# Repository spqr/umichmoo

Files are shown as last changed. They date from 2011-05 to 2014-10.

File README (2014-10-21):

https://spqr.eecs.umich.edu/moo/

For licensing information, see license.txt.

This code is known to work only with IAR Embedded Workbench, including the
Kickstart (code size limited) edition available from TI.

= List of Compatible Readers =

* Impinj Speedway
* Impinj Speedway Revolution
* ThingMagic Mercury 5
* ThingMagic Mercury 5e
* ThingMagic Mercury 6
* Michael Buettner's GNU Radio gen2_rfid reader (YMMV)

See README.usage for information on compiling and flashing the moo.

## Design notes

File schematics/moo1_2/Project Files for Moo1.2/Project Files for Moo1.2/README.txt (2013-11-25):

Design Parameters

Material Type: FR4
Finish Thickness: 31 mil
Copper weight(inner): 1 oz
Copper Weight(outer): 2 oz
Silk Screen Color: Yellow
Solder Mask Color: Blue
Surface Finishing: HASL
Would like Electrical Testing performed

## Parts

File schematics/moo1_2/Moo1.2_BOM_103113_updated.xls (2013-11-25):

BOM: Moo 1.2
Assembly Part Number/Revision: Moo Rev: 1.2
Customer Company Name: U of M / SPQR Lab
Date Updated: 10/31/13
 |  |  | (fill this column only in case you also give your own part numbers) |  |  |  |  |  |  |  | (fill this column only in case of consigned) | (fill this column only in case of consigned)
Item # | Qty/ bd | Reference designations | Customer Part # | Value | Size / Footprint | Part description/ specs | Manfacturer | Manufacturer Part # | Distributor | Distributor P/N | Quantity Required | Kit Quantity Shipped | ASSEMBLY / PROCUREMENT COMMENTS
1 | 2 | C1, C6 |  | 10uF | C0805 | CAP CER 10UF 16V 10% X5R 0805 | AVX Corporation | 0805YD106KAT2A | Digi-Key | 478-5165-1-ND |  |  | C6 is an 0402 capacitor
2 | 4 | C2, C4, C5, C13 |  | 0.1uF | C0402 | CAP CER 0.1UF 16V 10% X7R 0402 | TDK Corporation | C1005X7R1C104K | Digi-Key | 445-4952-1-ND |  |  | removed C9 part
3 | 6 | C10, C11, Cp1, Cp2, Cp3, Cp4 |  | 10pF | C0402 | CAP CER 10PF 50V 5% NP0 0402 | Murata Electronics | GRM1555C1H100JA01D | Digi-Key | 490-5921-1-ND
4 | 1 | C12 |  | 100pF | C0402 | CAP CER 100PF 50V 5% NP0 0402 | Murata Electronics | GRM1555C1H101JZ01D | Digi-Key | 490-6153-1-ND
5 | 2 | C3, C14, C20 |  | 1uF | C0402 | CAP CER 1UF 10V 10% X5R 0402 | Murata Electronics | GRM155R61A105KE15D | Digi-Key | 490-3890-1-ND |  |  | DNI C3
6 | 5 | Cs1, Cs2, Cs3, Cs4, Cs5 |  | 7pF | C0402 | Ceramic Capacitor - Standard, 7pF | Murata Electronics | GRM1555C1H7R0DZ01D | Digi-Key | 490-1277-1-ND
7 | 1 | CV1 |  | 7pF-30pF | C0603 | CAP TRIMMER 7-30PF 25V SMD | Sprague-Goodman (http://digikey.com/Suppliers/us/Sprague-Goodman.page?lang=en) | GKRP30066 | Digi-Key | SG2029CT-ND
8 | 5 | D1, D2, D3, D4, D5 |  |  | SOT-323 | DIODE SCHOTTKY DETECT SS SOT-323 | Avago Technologies | HSMS-285C-BLKG | Digi-Key | 516-2558-ND
9 | 2 | D6, D7 |  |  | SOD-523 | SCHOTTKY RECTIFIER, 30mA, 40V, SOD-523 | ON Semiconductor | RB751S40T1G | Newark | 10N9732
10 | 1 | DA1 |  |  | O603 | LED 630NM RED WTR CLR 0603 SMD | Rohm Semiconductor | SML-311UTT86 | Digi-Key | 511-1304-1-ND
11 | 1 | ED |  |  | SOD-523 | 5V Overvoltage Protection Zener | ON Semiconductor | ESD5Z3.3T1G | Digi-Key | ESD5Z3.3T1GOSCT-ND
12 | 1 | L1 |  | 6.8 nH | O603 | Inductor, 6.8nH | Panasonic | ELJ-RE6N8JFA | Digi-Key | PCD1971CT-ND
13 | 1 | MCU1 |  |  | 64-LQFP | 64PM MSP430F2618 | TI | MSP430F2618TPMR | Digi-Key | 296-22697-1-ND
14 | 1 | P1, P2, P3, P4 |  |  |  | Header, 10-Pin |  | 851-93-050-20-001000 | Digi-Key | ED8850-ND |  |  | DNI P1, P2, P3, P4
15 | 1 | Q1 |  |  | SOT23 | NPN 5 GHz wideband transistor | NXP Semiconductors | BFT25A,215 | Digi-Key | 568-1992-1-ND
16 | 3 | Q2, Q3, Q5 |  |  | SOT-723 | Power MOSFET N-CH 20V 750MA SOT-723 | ON Semiconductor | NTK3134NT1G | Digi-Key | NTK3134NT1GOSCT-ND
17 | 1 | Q4 |  |  | CMPAK-4 | Transistors RF MOSFET N-CH DUAL GATE 6V | NXP Semiconductors | BF1212WR,115 | Mouser | 771-BF1212WR
18 | 1 | R1 |  | 0 ohm | O402 | RES 0.0 OHM 1/10W JUMP 0402 SMD | Panasonic | ERJ-2GE0R00X | Digi-Key | P0.0JCT-ND
19 | 2 | R2, R4 |  | 1 k ohm | O402 | RES 1K OHM 1/10W 1% 0402 SMD | Panasonic | ERJ-2RKF1001X | Digi-Key | P1.00KLCT-ND
20 | 1 | R3 |  | 2k ohm | O402 | RES 2K OHM 1/10W 5% 0402 SMD | Panasonic | ERJ-2GEJ202X | Digi-Key | P2.0KJCT-ND
21 | 1 | R5 |  | 100 ohm | O402 | RES 100 OHM 1/16W 1% 0402 SMD | Vishay Dale | CRCW0402100RFKED | Digi-Key | 541-100LCT-ND
22 | 2 | R6, R17 |  | 33k ohm | O402 | RES 33.0K OHM 1/16W 1% 0402 SMD | Vishay Dale | CRCW040233K0FKED | Digi-Key | 541-33.0KLCT-ND
23 | 2 | R10, R11 |  | 10k ohm | O402 | RES 10K OHM 1/10W 1% 0402 SMD | Panasonic | ERJ-2RKF1002X | Digi-Key | P10.0KLCT-ND
24 | 1 | R16 |  | 200k ohm | O402 | RES 200K OHM 1/10W 1% 0402 SMD | Panasonic | ERJ-2RKF2003X | Digi-Key | P200KLCT-ND
25 | 1 | R18 |  | 1M ohm | O402 | RES 1M OHM 1/10W 1% 0402 SMD | Panasonic | ERJ-2RKF1004X | Digi-Key | P1.00MLCT-ND
26 | 1 | R19 |  | 66k ohm | O402 | RES 66.5K OHM 1/10W 1% 0402 SMD | Panasonic | ERJ-2RKF6652X | Digi-Key | P66.5KLCT-ND
27 | 1 | Rs |  | 10 ohm | O603 | RES 10 OHM 1/10W .1% 0603 SMD | Bourns Inc. | CRT0603-BY-10R0ELF | Digi-Key | CRT0603-BY-10R0ELFCT-ND
28 | 1 | TMP |  |  | 6-TSSOP (5 Lead) | Analog Temperature Sensor | TI | LM94021BIMGX/NOPB | Digi-Key | LM94021BIMGX/NOPBCT-ND
29 | 1 | U1 |  |  | SC70-5 | IC COMPARATOR LV LP OD SC70-5 | ON Semiconductor | NCS2200SQ2T2G | Digi-Key | NCS2200SQ2T2GOSCT-ND
30 | 2 | U2, U4 |  |  | 6-UFDFN | Level Shifter: 1-Bit Dual-Supply Non-Inverting Level Translator | ON Semiconductor | NLSV1T244MUTBG | Digi-Key | NLSV1T244MUTBGOSCT-ND
31 | 1 | U3 |  |  | SC82-AB | Ultra-Low Iq 150mA CMOS LDO Regulator with Enable, 1.8V, SC82-AB | ON Semiconductor | NCP583SQ18T1G | Digi-Key | NCP583SQ18T1GOSCT-ND
32 | 1 | U5 |  |  | 5-TSOP | IC VOLT DETECT CMOS 2.0V 5TSOP | ON Semiconductor | NCP300LSN20T1G | Digi-Key | NCP300LSN20T1GOSCT-ND
33 | 1 | U6 |  |  | SC70-5 | IC SWITCH SPST SC70-5 | TI | TS5A3166DCKR | Digi-Key | 296-17741-1-ND
34 | 1 | U7 |  |  | 8-SOIC | 4Mb 40MHz SPI 8-Lead SOIC Flash | TI | SST25WF040-40-5I-SAF | Digi-Key | SST25WF040-40-5I-SAF-ND
35 | 1 | XL1 |  |  | 16-LGA | IC ACCEL DIG LO PWR 3AX 16LGA | Analog Devices | ADXL362BCCZ-R2 | Digi-Key | ADXL362BCCZ-R2TR-ND |  |  | Updated XL to XL1
36 | 1 | Y1 |  |  | 3.2mm x 1.5mm | FC-135 Crystal D-K SE2416CT (MC-146), 32KHz Crystal | Epson | FC-135 32.7680KA-A3 | Digi-Key | SE2413CT-ND
37 | 1 | PCB |  |  |  | Moo 1.2 PCB
 | 62 | TOTAL # of Components
DNI LIST ("DO NOT INSTALL" LIST)
 | 1 | C3
 | 4 | P1,P2, P3, P4
 | 5 | TOTAL DNI

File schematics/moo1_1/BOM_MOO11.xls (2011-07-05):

Part Name / Manufacturer ID | Designator | Description | Quantity Needed | Quantity Available
0805YD106KAT2A | C1 | Ceramic Capacitor - Standard, 10uF | 10 | 22
C1005X7R1C104K | C2, C4, C5, C6, C9, C13 | Ceramic Capacitor - Standard, 0.1uF | 60 | 100
GRM1555C1H100JZ01D | C10, C11, Cp1, Cp2, Cp3, Cp4 | Ceramic Capacitor - Standard, 10pF | 60 | 69
GRM1555C1H101JZ01D | C12 | Ceramic Capacitor - Standard, 100pF | 10 | 20
GRM155R61A105KE15D | C14, C20 | Ceramic Capacitor - Standard, 1uF | 20 | 27
GRM1555C1H7R0DZ01D | Cs1, Cs2, Cs3, Cs4, Cs5 | Ceramic Capacitor - Standard, 7pF | 50 | 60
GKRP20066 | CV1 | Variable Capacitor 603 Compatible, DK: 490-2009 & SG2026CT, 5~20pF | 10 | 15
HSMS-285C-BLK | D1, D2, D3, D4, D5 | Agilent Schottky Diode, Bridge Quad, HSMS-285C, Vrrm = 2V | 50 | 100
RB751S40T1G | D6, D7 | Agilent Schottky Diode, Bridge Quad, HSMS-285C, Schottky Diode, Vr = 30V | 20 | 22
SML-311UTT86 | DA1 | LED 630NM RED WTR CLR 0603 SMD | 10 | 12
ESD5Z3.3T1G | ED | 5V Overvoltage Protection Zener | 10 | 15
ELJ-RE6N8JFA | L1 | Inductor, 6.8nH | 10 | 26
MSP430F2618TPMR | MCU1 | 64PM MSP430F2618 | 10 | 10
851-93-050-20-001000 | P1 | Header, 10-Pin | 100 | 125
BFT25A,215 | Q1 | NPN 5 GHz wideband transistor | 10 | 10
NTK3134NT1G | Q2, Q3, Q5 | Power MOSFET 20V, 890mA, single N-channel | 30 | 33
BF1212WR,115 | Q4 | N-Channel Dual Gate Transistor | 10 | 22
ERJ-2GE0R00X | R1 | Thick Film Chip Resistor, 0 ohm | 10 | 12
ERJ-2RKF1001X | R2, R4 | Thick Film Chip Resistor, 1k ohm | 20 | 30
ERJ-2GEJ202X | R3 | Thick Film Chip Resistor, 2k ohm | 10 | 12
CRCW0402100RFKED | R5 | Thick Film Chip Resistor, 100 ohm | 10 | 29
CRCW040233K0FKED | R6, R17 | Thick Film Chip Resistor, 33k ohm | 20 | 22
ERJ-2RKF1002X | R10, R11 | Thick Film Chip Resistor, 10k ohm | 20 | 22
ERJ-2RKF2003X | R16 | Thick Film Chip Resistor, 200k ohm | 10 | 22
ERJ-2RKF1004X | R18 | Thick Film Chip Resistor, 1M ohm | 10 | 30
ERJ-2RKF6652X | R19 | Thick Film Chip Resistor, 66k ohm | 10 | 12
CRT0603-BY-10R0ELF | Rs | RES 10 OHM 1/10W .1% 0603 SMD | 10 | 14
LM94021 | TMP | Temperature Sensor | 10 | 12
NCS2200SQ2T2G | U1 | On Semi 10uA Comparator | 10 | 12
NLSV1T244MUTBG | U2, U4 | Level Shifter: 1-Bit Dual-Supply Non-Inverting Level Translator | 20 | 22
NCP583SQ18T1G | U3 | Ultra-Low Iq 150mA CMOS LDO Regulator with Enable, 1.8V, SC82-AB | 10 | 10
S-1000C20-I4T1G | U5 | Ultra-small package High precision protection(SNT-4A) | 10 | 22
TS5A3166 | U6 | TI Analog Switch 100nA 1ohm Normally Open | 10 | 22
SST25WF040-40-5I-SAF | U7 | 4Mb 40MHz SPI 8-Lead SOIC Flash | 10 | 10
ADXL330 | XL | Analog Devices 3-axis accelerometer | 10 | 10
FC-135 32.7680KA-A3 | Y1 | FC-135 Crystal D-K SE2416CT (MC-146), 32KHz Crystal | 10 | 10
 | PCB | Moo 1.1 PCB | 10 | 10

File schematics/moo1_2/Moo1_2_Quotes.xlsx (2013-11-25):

PCB Quotes for Moo 1.2 | Note: Fab prices are going to be the same for 1-50 boards so we should order the maximum number at that rate and only assembly a couple |  |  |  |  |  |  |  |  | Assembly Price Not included
 |  |  |  |  |  | includes cost of components
Vendor | Turn-time Fab/Assembly | Fab Qty | Fabrication Price per board | Filled Vias? | Assemble Qty | Assembly Price | Tooling NRE? | Elec Testing? | Per Board Price | Total Price | Notes
Sunstone / Screaming Circuits | 5 days | 50 | $28.20 | No |  |  | 0 | yes | $28.20 | $1410.00 | plus 10% off on first order
Sierra Circuits | 5 days | 10 | $103.50 | No | 10 | $204.46 | 0 |  | $307.96 | $3079.60
Sierra Circuits | 7 days/5 days | 10 | $166.60 | Yes | 10 | $204.46 | 0 | yes | $371.06 | $3710.60
Sierra Circuits | 7 days/5 days | 10 | $166.60 | Yes | 2 | $608.99 | $0.00 | yes | $775.59 | $2883.98
Advanced Circuits (Custom Spec) | 7 days | 5 | $211.55 | No |  |  | $300 |  | $211.55 | $1057.75
PCB Fab Express | 5 days | 40 | $28.75 | No | 2 | $623.15 | 0 | Yes | $651.90 | $2396.30
PCB Fab Express | 5 days | 40 | $28.75 | no | 5 | $326.35 | $0.00 | yes | $355.10 | $2781.75
PCB Fab Express | 5 days | 40 | $28.75 | no | 10 | $219.43 | $0.00 | yes | $248.18 | $3344.30

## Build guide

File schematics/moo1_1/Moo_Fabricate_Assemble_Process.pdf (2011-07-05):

### Procedure of Fabricating and Assembling UMass Moo 1.1

Fabrication of Moo PCB:
1. To fabricate Moo PCBs, a bunch of Gerber files and some fabrication setting options are needed.
2. Contact a PCB factor to ask for a price, such as Sierra ProtoExpress. An email to rosyb@protoexpress.com can be sent to ask for a quotation. The email should include:
a) Quantity: such as 10, 100, 1000
b) # of days: such as 3, 4, 5, or more
c) Material Type: FR4
d) Finish thickness: 31 mil.
e) Copper Weight (inner): 1oz
f) Copper Weight (outer): 2oz
g) Silk Screen Color: White
h) Solder Mask Color: Green
i) Surface finishing: HASL
j) The Gerber files of Moo as attachments. The following contents will talk about how to obtain these files.
3. Download the Moo hardware design file package Moo1.1_03102011.zip from URL: http://www.github.com/spqr/umassmoo
4. Uncompressed the package, all gerber files needed to fabricate Moo PCBs are in the directory of Moo1.1_03102011\Gerbers.
5. If you want to do change of PCB layout and generate new gerber files, the following steps are needed:
a) Install a CAD software to design Schematics and PCBs, such as Altium Designer Winter 2009, or later version.
b) Use the Altium Designer software to edit the PCB layout of Moo.
c) Export new gerber files by following the tutorial of URL: http://www.olimex.com/pcb/How%20to%20export%20Gerber%20files%20from%20A ltium%20Designer%202009.pdf

Assemble of Moo:
1. Assembling is a procedure of soldering the parts onto the print circuit board. The obtaining of Moo PCB has already been described above. The other parts can be obtained in any one of two ways:
1) Purchase by yourself;
2) Some PCB assemblers provide service of parts purchasing/collecting service.

2. A bill of materials (BOM) is necessary to collecting the parts. The BOM of Moo is attached at the end of this document.
3. If you want to purchase the parts by yourself, you order everything listed in the BOM, otherwise, you need buy the service of the assembler, the factor which provides PCB assembling services for you.
4. Contact an assembler to ask for a quotation, such as Sierra ProtoExpress. In the email, the following documents should be sent as attachments:
d) PDF file of your PCB
e) Bill Of Materials (BOM), which includes part manufacturer #, designator, description, quantity.
5. Once got the PCBs and all parts, and quotation for assembling, mail the PCBs and parts in one box to assembler and just wait for the return of them.

Fabrication And Assembling of UMass Moo Version 1.1

Part Name / Manufacturer
ID | Designator | Description

Quantity
Needed

Quantity
Available
0805YD106KAT2A | C1 | Ceramic Capacitor - Standard, 10uF | 10 | 22
C1005X7R1C104K | C2, C4, C5, C6, C9, C13 | Ceramic Capacitor - Standard, 0.1uF | 60 | 100
GRM1555C1H100JZ01D | C10, C11, Cp1, Cp2, Cp3, Cp4 | Ceramic Capacitor - Standard, 10pF | 60 | 69
GRM1555C1H101JZ01D | C12 | Ceramic Capacitor - Standard, 100pF | 10 | 20
GRM155R61A105KE15D | C14, C20 | Ceramic Capacitor - Standard, 1uF | 20 | 27
GRM1555C1H7R0DZ01D | Cs1, Cs2, Cs3, Cs4, Cs5 | Ceramic Capacitor - Standard, 7pF | 50 | 60
GKRP20066 | CV1 | Variable Capacitor 603 Compatible, DK: 490-2009 & SG2026CT, 5~20pF | 10 | 15
HSMS-285C-BLK | D1, D2, D3, D4, D5 | Agilent Schottky Diode, Bridge Quad, HSMS-285C, Vrrm = 2V | 50 | 100
RB751S40T1G | D6, D7 | Agilent Schottky Diode, Bridge Quad, HSMS-285C, Schottky Diode, Vr = 30V | 20 | 22
SML-311UTT86 | DA1 | LED 630NM RED WTR CLR 0603 SMD | 10 | 12
ESD5Z3.3T1G | ED | 5V Overvoltage Protection Zener | 10 | 15
ELJ-RE6N8JFA | L1 | Inductor, 6.8nH | 10 | 26
MSP430F2618TPMR | MCU1 | 64PM MSP430F2618 | 10 | 10
851-93-050-20-001000 | P1 | Header, 10-Pin | 100 | 125
BFT25A,215 | Q1 | NPN 5 GHz wideband transistor | 10 | 10
NTK3134NT1G | Q2, Q3, Q5 | Power MOSFET 20V, 890mA, single N-channel | 30 | 33
BF1212WR,115 | Q4 | N-Channel Dual Gate Transistor | 10 | 22
ERJ-2GE0R00X | R1 | Thick Film Chip Resistor, 0 ohm | 10 | 12

Fabrication And Assembling of UMass Moo Version 1.1

ERJ-2RKF1001X | R2, R4 | Thick Film Chip Resistor, 1k ohm | 20 | 30
ERJ-2GEJ202X | R3 | Thick Film Chip Resistor, 2k ohm | 10 | 12
CRCW0402100RFKED | R5 | Thick Film Chip Resistor, 100 ohm | 10 | 29
CRCW040233K0FKED | R6, R17 | Thick Film Chip Resistor, 33k ohm | 20 | 22
ERJ-2RKF1002X | R10, R11 | Thick Film Chip Resistor, 10k ohm | 20 | 22
ERJ-2RKF2003X | R16 | Thick Film Chip Resistor, 200k ohm | 10 | 22
ERJ-2RKF1004X | R18 | Thick Film Chip Resistor, 1M ohm | 10 | 30
ERJ-2RKF6652X | R19 | Thick Film Chip Resistor, 66k ohm | 10 | 12
CRT0603-BY-10R0ELF | Rs | RES 10 OHM 1/10W .1% 0603 SMD | 10 | 14
LM94021 | TMP | Temperature Sensor | 10 | 12
NCS2200SQ2T2G | U1 | On Semi 10uA Comparator | 10 | 12
NLSV1T244MUTBG | U2, U4 | Level Shifter: 1-Bit Dual-Supply Non-Inverting Level Translator | 20 | 22
NCP583SQ18T1G | U3 | Ultra-Low Iq 150mA CMOS LDO Regulator with Enable, 1.8V, SC82-AB | 10 | 10
S-1000C20-I4T1G | U5 | Ultra-small package High precision protection(SNT-4A) | 10 | 22
TS5A3166 | U6 | TI Analog Switch 100nA 1ohm Normally Open | 10 | 22
SST25WF040-40-5I-SAF | U7 | 4Mb 40MHz SPI 8-Lead SOIC Flash | 10 | 10
ADXL330 | XL | Analog Devices 3-axis accelerometer | 10 | 10
FC-135 32.7680KA-A3 | Y1 | FC-135 Crystal D-K SE2416CT (MC-146), 32KHz Crystal | 10 | 10
| PCB | Moo 1.1 PCB | 10 | 10

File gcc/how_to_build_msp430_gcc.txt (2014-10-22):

1. Install the compiler for cross compiling

sudo add-apt-repository ppa:ubuntu-toolchain-r/test
sudo apt-get update
sudo apt-get install g++-4.9 gcc-4.9
(http://askubuntu.com/questions/428198/getting-installing-gcc-g-4-9-on-ubuntu)

2. Install tools required for cross compiling
sudo apt-get install libgmp3-dev libmpfr-dev libisl-dev libcloog-isl-dev libmpc-dev
(http://wiki.osdev.org/GCC_Cross-Compiler)

3. Setup build environmnet
mkdir -p $HOME/opt/cross
mkdir -p $HOME/src

export PREFIX="$HOME/opt/cross"
export TARGET=msp430-elf
export PATH="$PREFIX/bin:$PATH"

4. Build Binutils
cd $HOME/src
wget ftp://sourceware.org/pub/binutils/snapshots/binutils-2.24.51.tar.bz2
tar xvf binutils-2.24.51.tar.bz2
mkdir build_binutils_msp430
cd build_binutils_msp430
CC=/usr/bin/gcc-4.9 CXX=/usr/bin/g++-4.9 ../binutils-2.24.51/configure --prefix=${PREFIX} --target=${TARGET}
make -j8
make install
cd ..

5. Build GCC
wget http://mirror.csclub.uwaterloo.ca/gnu/gcc/gcc-4.9.1/gcc-4.9.1.tar.bz2
tar xvf gcc-4.9.1.tar.bz2
mkdir build_gcc_msp430
cd build_gcc_msp430
CC=/usr/bin/gcc-4.9 CXX=/usr/bin/g++-4.9 ../gcc-4.9.1/configure --prefix=${PREFIX} --target=${TARGET} --with-newlib --enable-languages=c,c++
make all-host -j8
make install-host
cd ..

6. Build Newlib
wget ftp://sourceware.org/pub/newlib/newlib-2.1.0.tar.gz
tar xvf newlib-2.1.0.tar.gz
mkdir build_newlib_msp430
cd build_newlib_msp430
CC=/usr/bin/gcc-4.9 CXX=/usr/bin/g++-4.9 ../newlib-2.1.0/configure --prefix=${PREFIX} --target=${TARGET} --disable-newlib-supplied-syscalls --enable-newlib-reent-small --disable-newlib-fvwrite-in-streamio --disable-newlib-fseek-optimization --disable-newlib-wide-orient --enable-newlib-nano-malloc --disable-newlib-unbuf-stream-opt --enable-lite-exit --enable-newlib-global-atexit --disable-nls
make
make install
cd ..

7. Build GCC round 2
cd build_gcc_msp430
make all-target
make install-target
cd ..

8. Build GDB
wget http://ftp.gnu.org/gnu/gdb/gdb-7.8.tar.xz
tar xvf gdb-7.8.tar.xz
mkdir build_gdb_msp430
cd build_gdb_msp430
CC=/usr/bin/gcc-4.9 CXX=/usr/bin/g++-4.9 ../gdb-7.8/configure --prefix=${PREFIX} --target=${TARGET}
make
make install

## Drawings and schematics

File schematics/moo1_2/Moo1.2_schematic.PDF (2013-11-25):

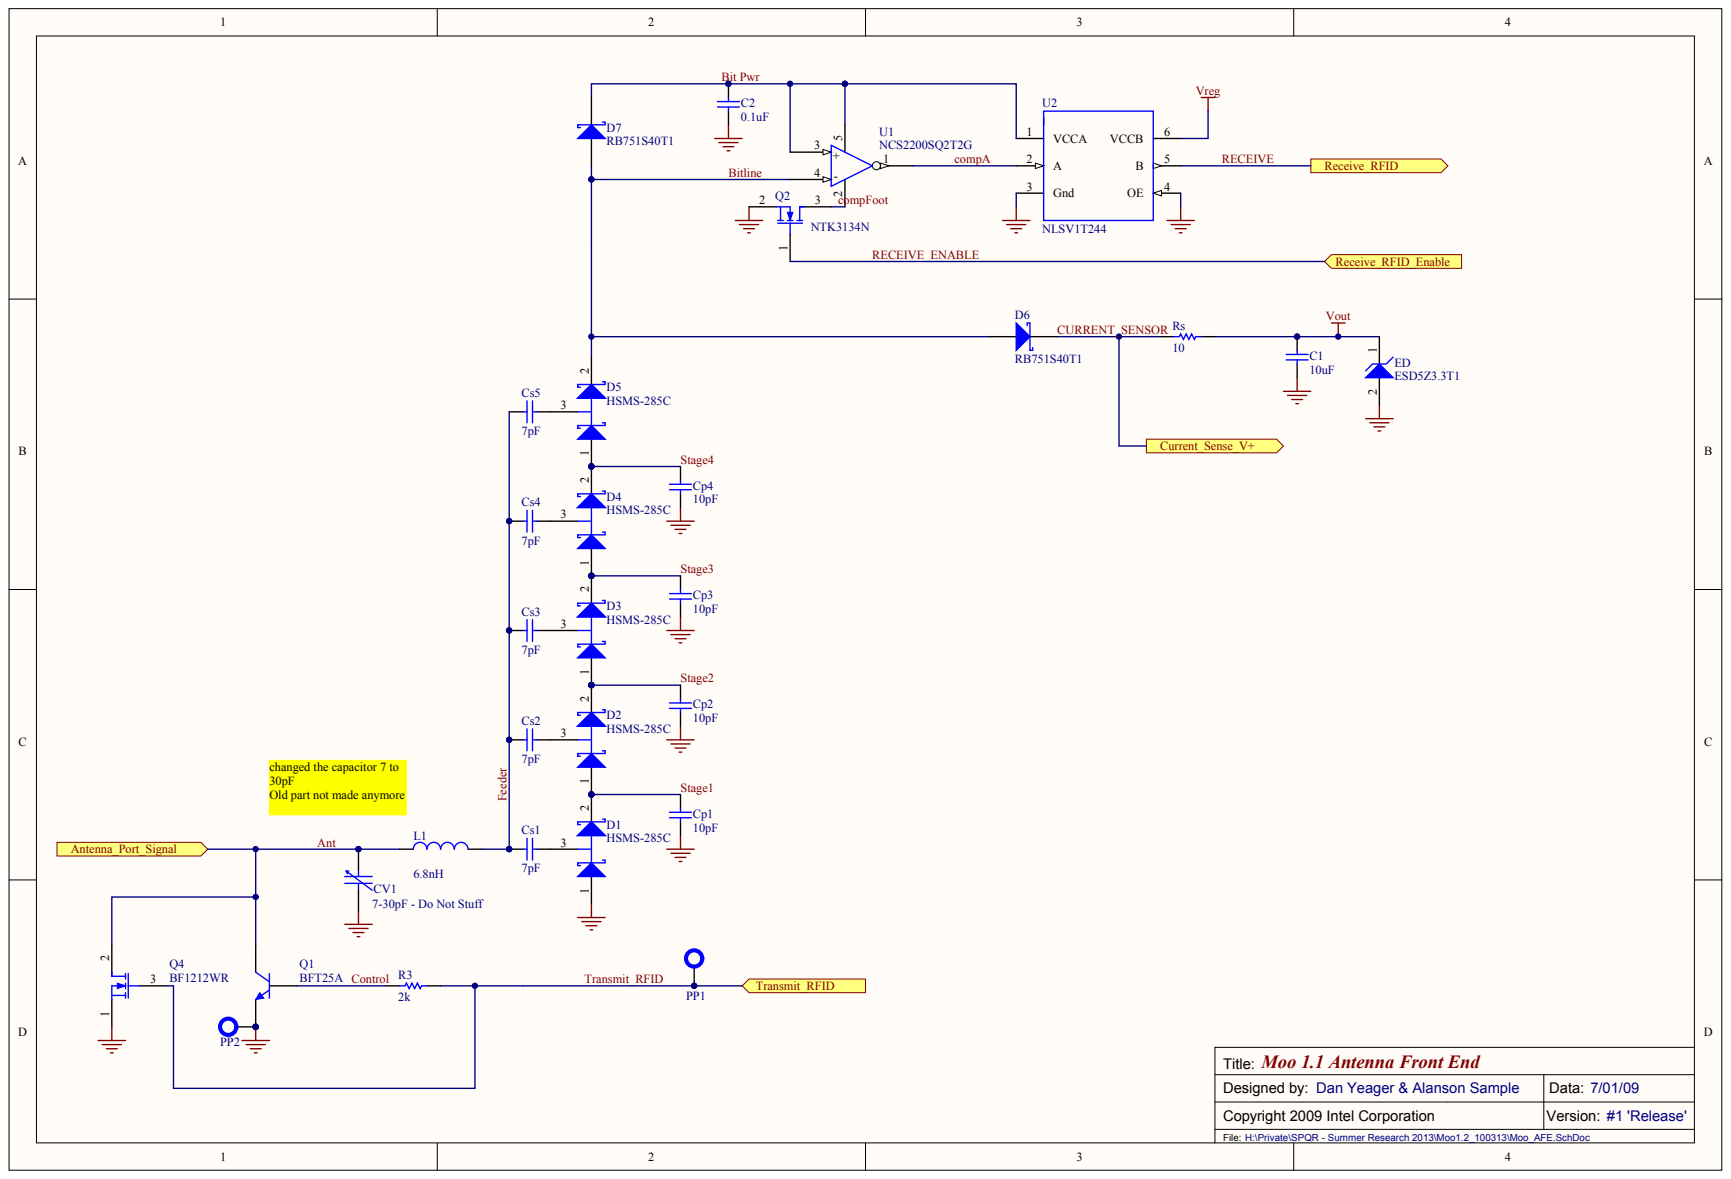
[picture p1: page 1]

changed the capacitor 7 to
Old part not made anymore

Title: Moo 1.1 Antenna Front End

Designed by: Dan Yeager & Alanson Sample | Data: 7/01/09

Copyright 2009 Intel Corporation | Version: #1 'Release'

H:\Private\SPQR - Summer Research 2013\Moo1.2_100313\Moo_AFE.SchDoc
File:

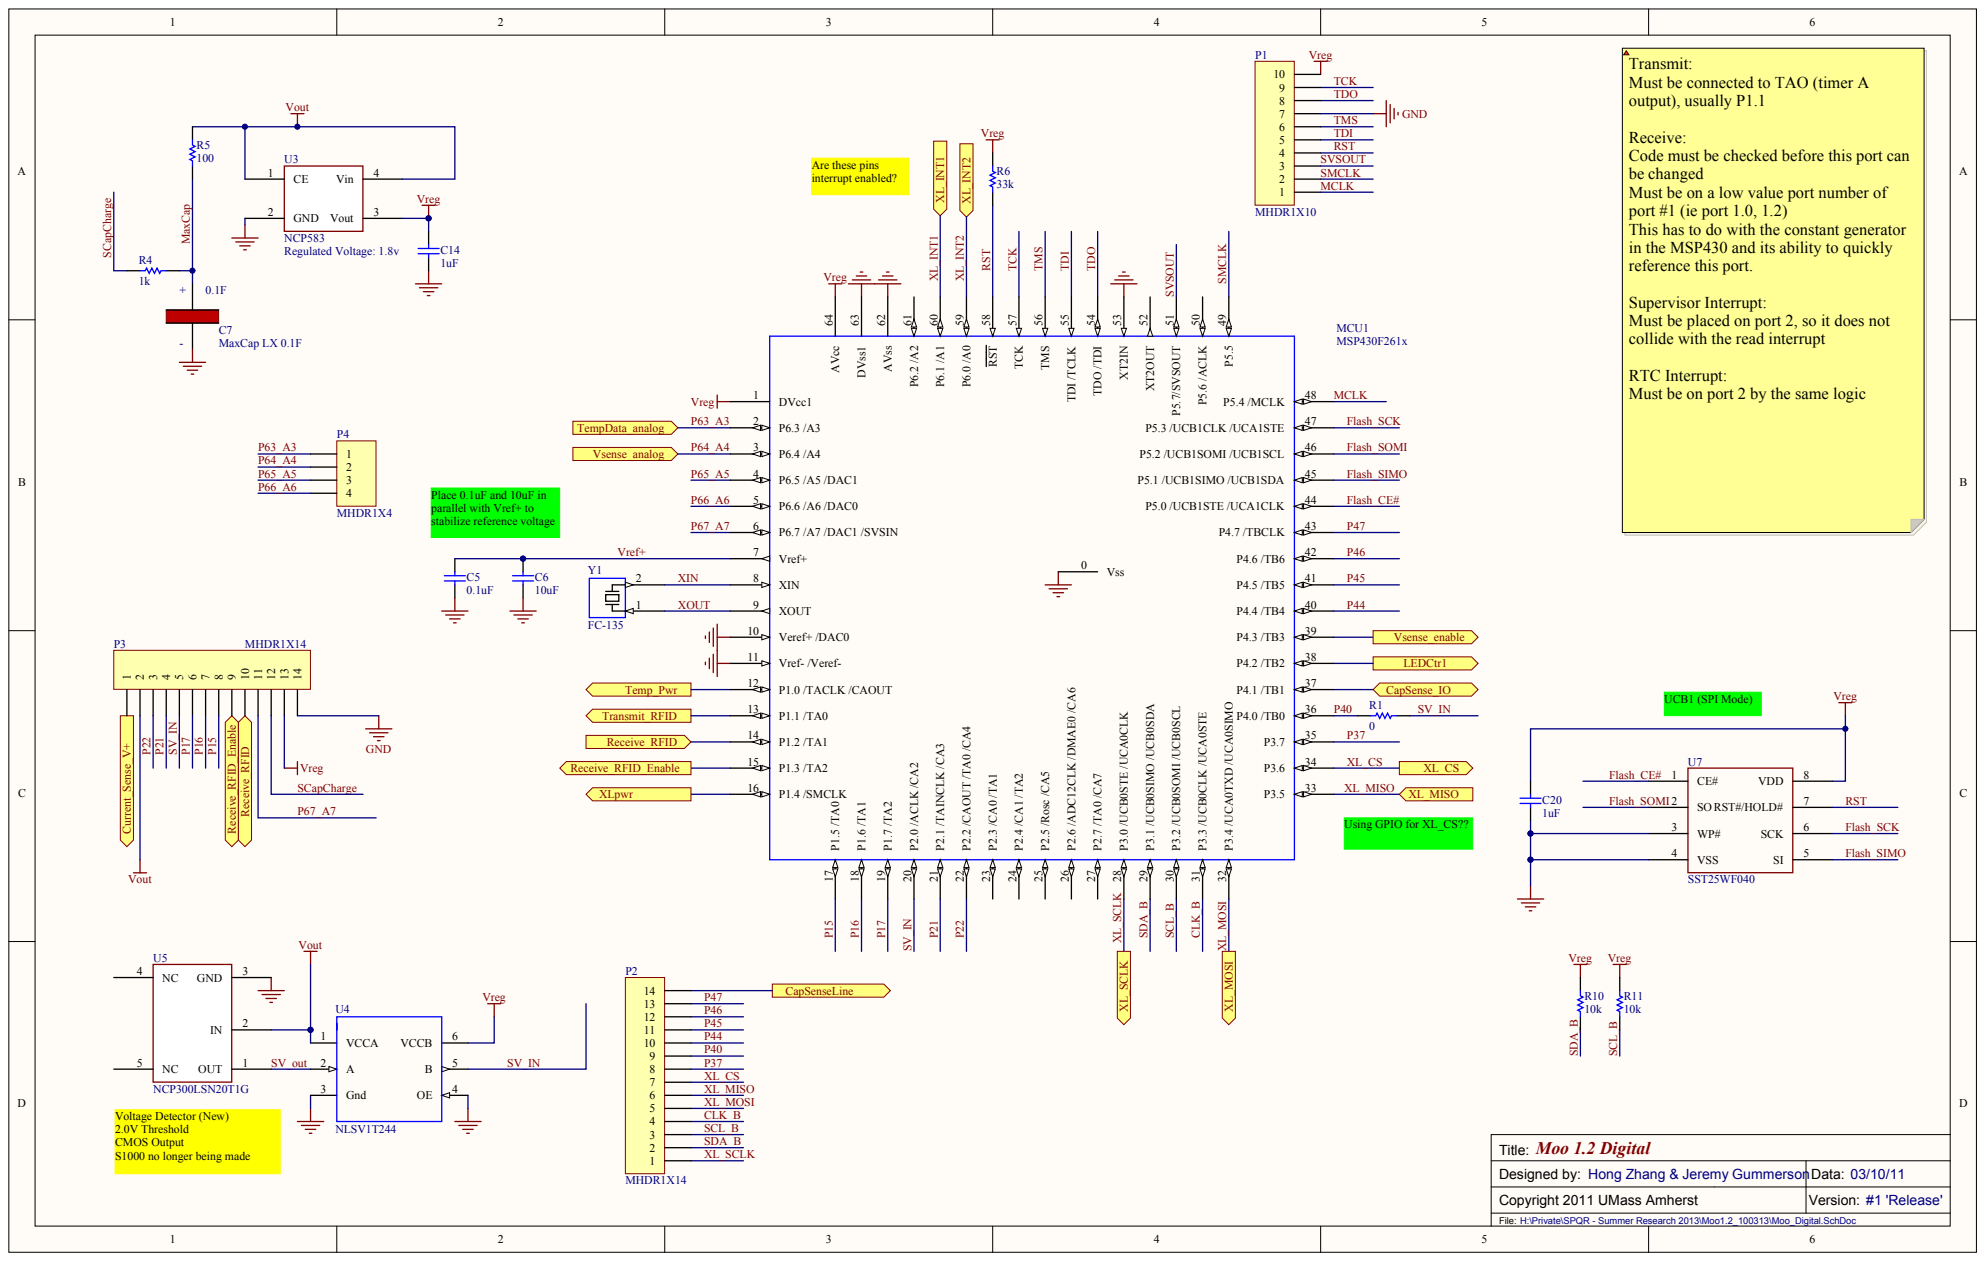
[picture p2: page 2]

Transmit:
Must be connected to TAO (timer A
output), usually P1.1

Receive:
Code
be changed
Must be on a low value port number of
port #1 (ie port 1.0, 1.2)
This has to do with the constant generator
in the MSP430 and its ability to quickly

must be checked before this port can

Supervisor Interrupt:
Must be placed on port 2, so it does not
collide with the read interrupt

RTC Interrupt:
Must be on port 2 by the same logic

Place 0.1uF and 10uF in
parallel with Vref+ to
stabilize reference v

Voltage Detector (New)
2.0V Threshold
CMOS Output
S1000 no longer being made

Designed by : Hong Zhang & Jerem y Gum mersonData: 03/10/11

Copyright 2011 UMass Amherst | Version: #1 'Release'

H:\Private\SPQR - Summer Research 2013\Moo1.2_100313\Moo_Digital.SchDoc
File:

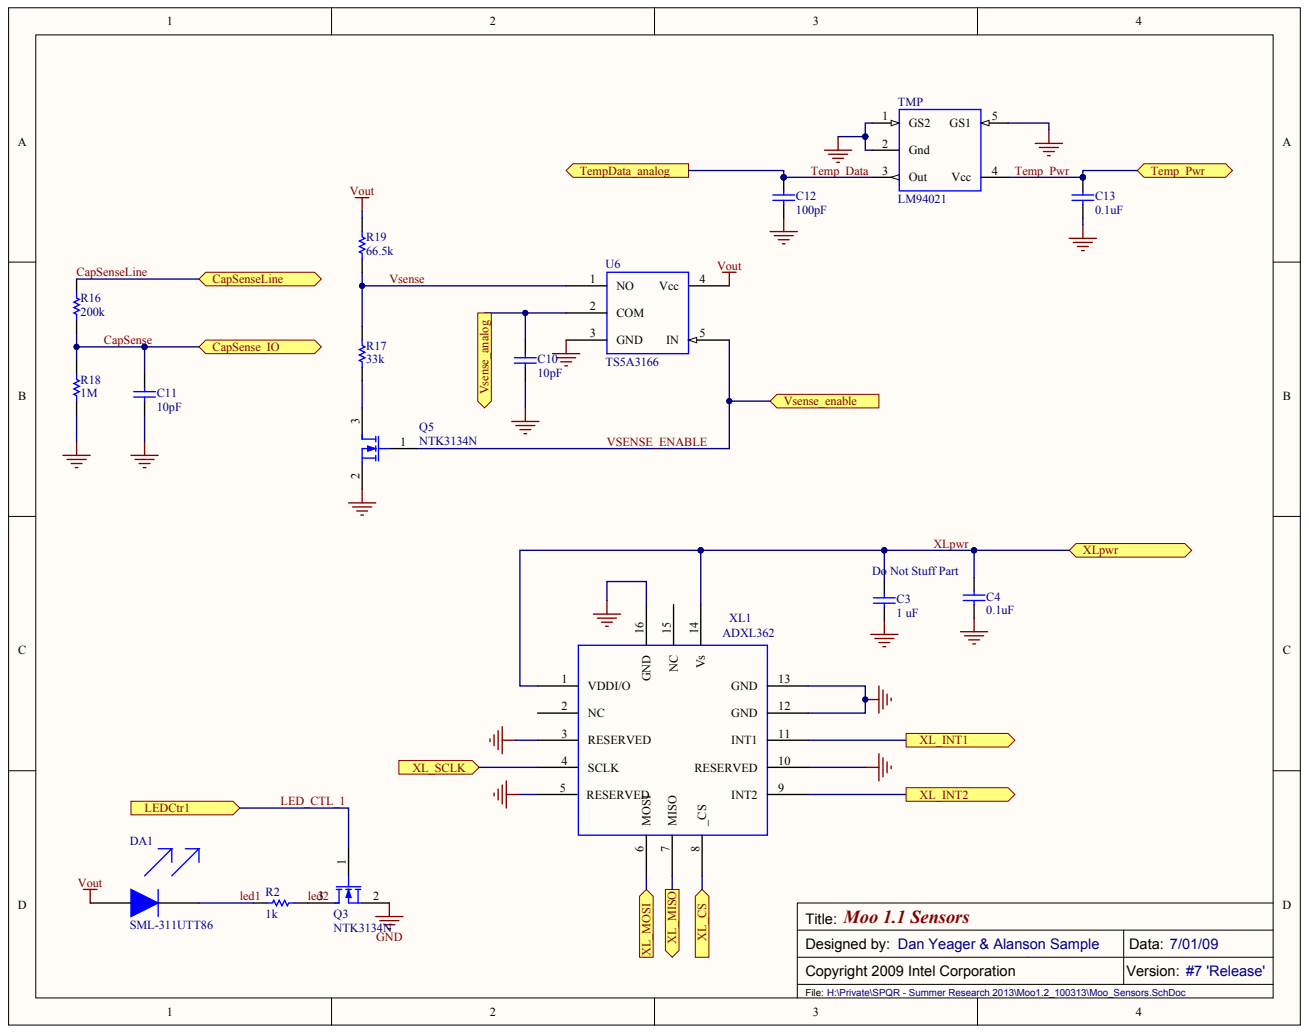
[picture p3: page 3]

COM 2 GND 3

Q5 NTK3134N | C10

Do Not Stuff Part

Designed by: Dan Yeager & Alanson Sample | Data: 7/01/09

Copyright 2009 Intel Corporation | Version: #7 'Release'

H:\Private\SPQR - Summer Research 2013\Moo1.2_100313\Moo_Sensors.SchDoc
File:

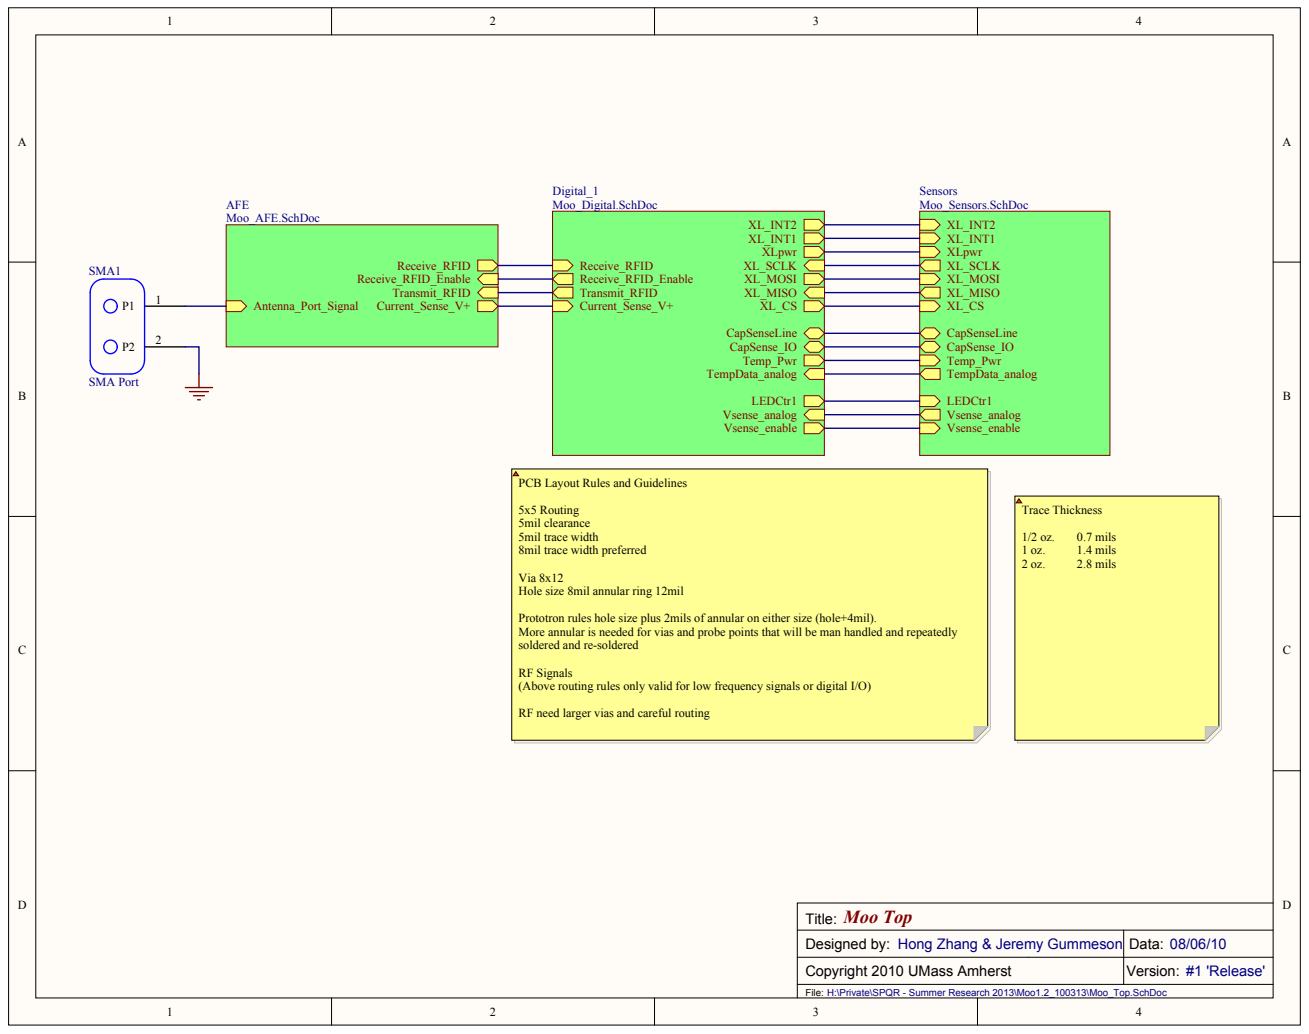
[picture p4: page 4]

PCB Layout Rules and Guidelines

Via 8x12
Hole size 8mil annular ring 12mil

Prototron rules hole size plus 2mils of annular on either size (hole+4mil).
More annular is needed for vias and probe points that will be man handled and repeatedly
soldered and re-soldered

RF Signals
(Above routing rules only valid for low frequency signals or digital I/O)

RF need larger vias and careful routing

Designed by: Hong Zhang & Jeremy Gummeson | Data: 08/06/10

Copyright 2010 UMass Amherst | Version: #1 'Release'

H:\Private\SPQR - Summer Research 2013\Moo1.2_100313\Moo_Top.SchDoc
File:

Component list | <Parameter Title not found>
Source Data From: | | Moo1.2.PrjPcb
Project: | | Moo1.2.PrjPcb
Variant: | | None
Report Date: | 10/9/2013 | 8:17:40 PM
Print Date: | 09-Oct-13 | 8:18:54 PM

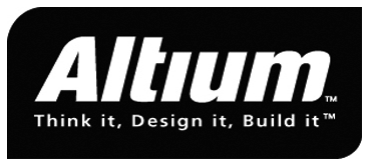
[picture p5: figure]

# | LibRef | #Column Name Error:Manufactu#Corerlumn Name Error:Manufact#uCor | lu mn Name Error:PartTyp | Description | Footprint | #Column Name Error:Package Reference | Quantity
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

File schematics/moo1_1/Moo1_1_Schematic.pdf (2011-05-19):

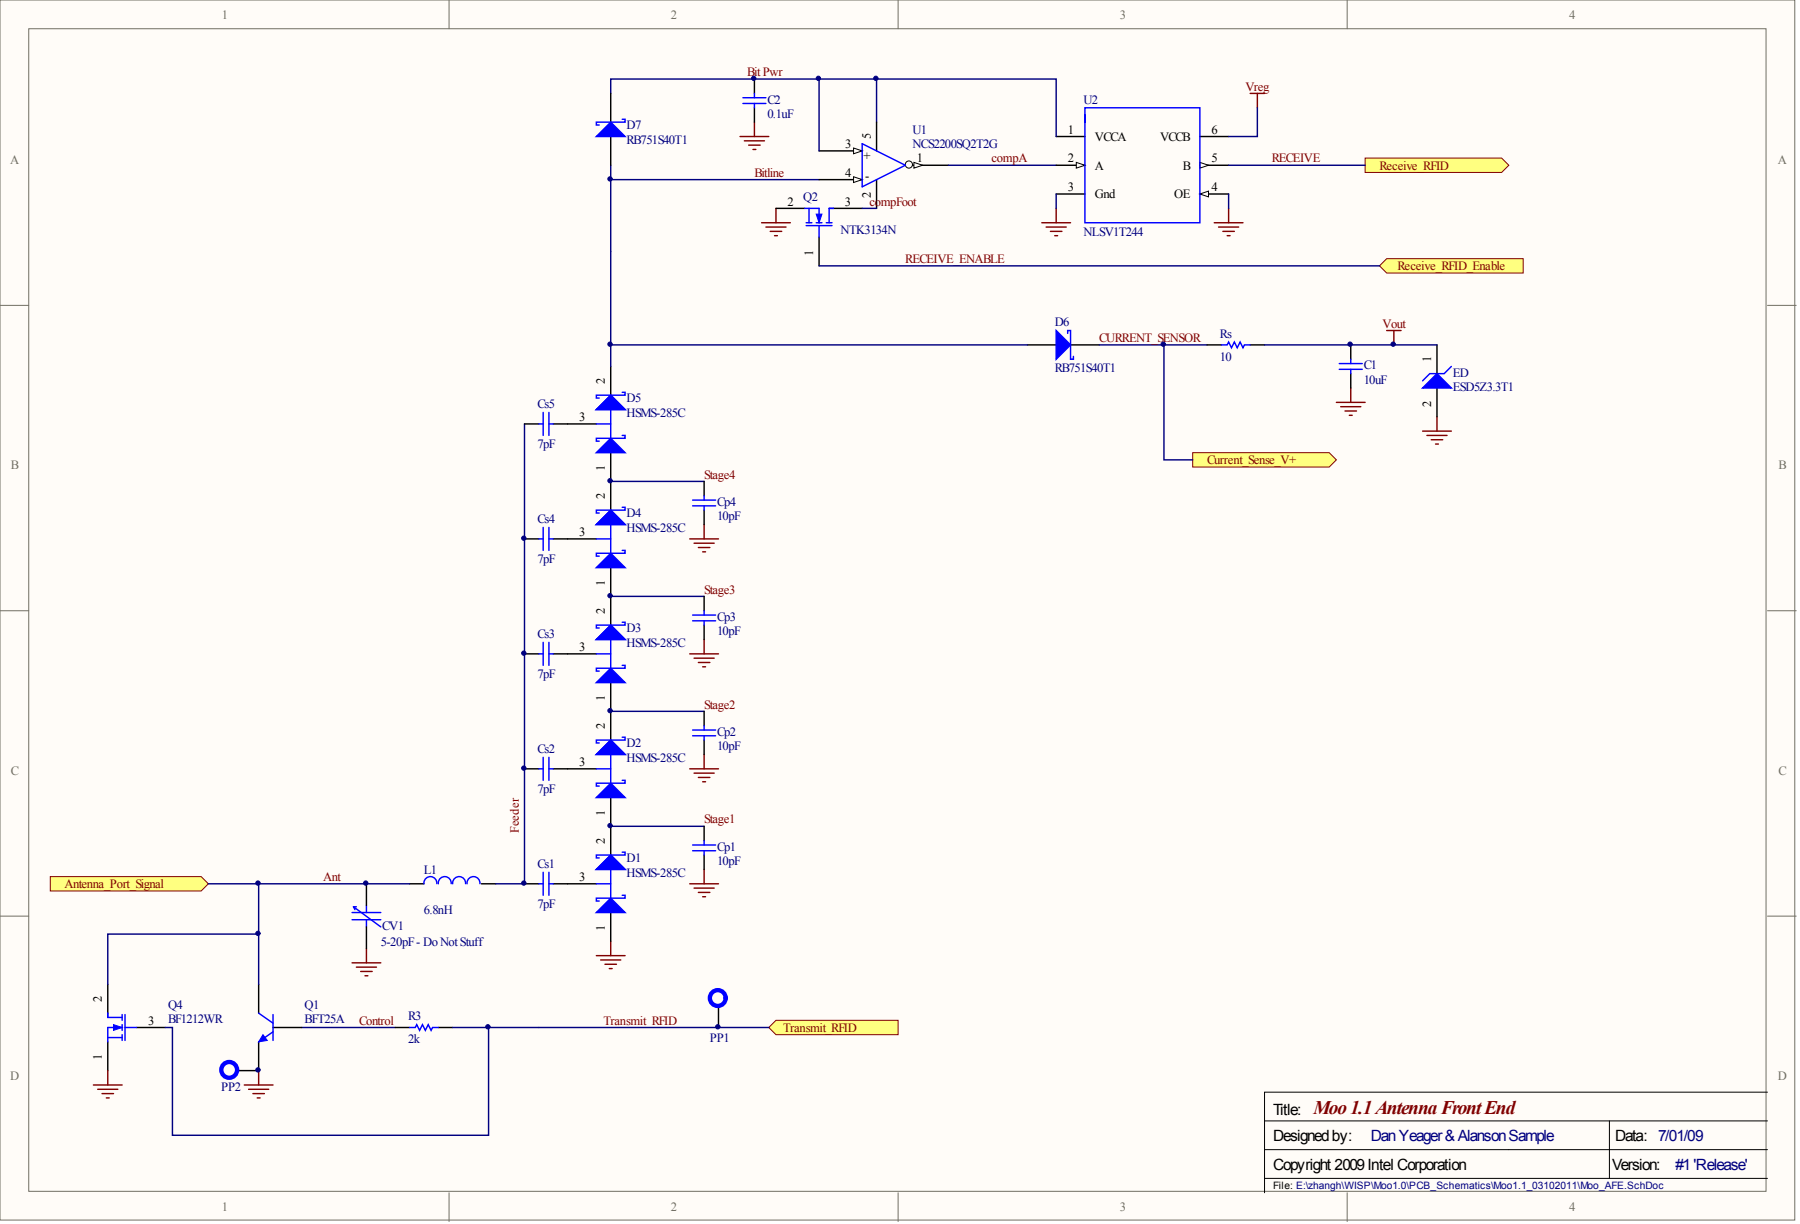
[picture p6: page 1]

Designed by: Dan Yeager & Alanson Sample | Data: 7/01/09

Copyright 2009 Intel Corporation | Version: #1 'Release'

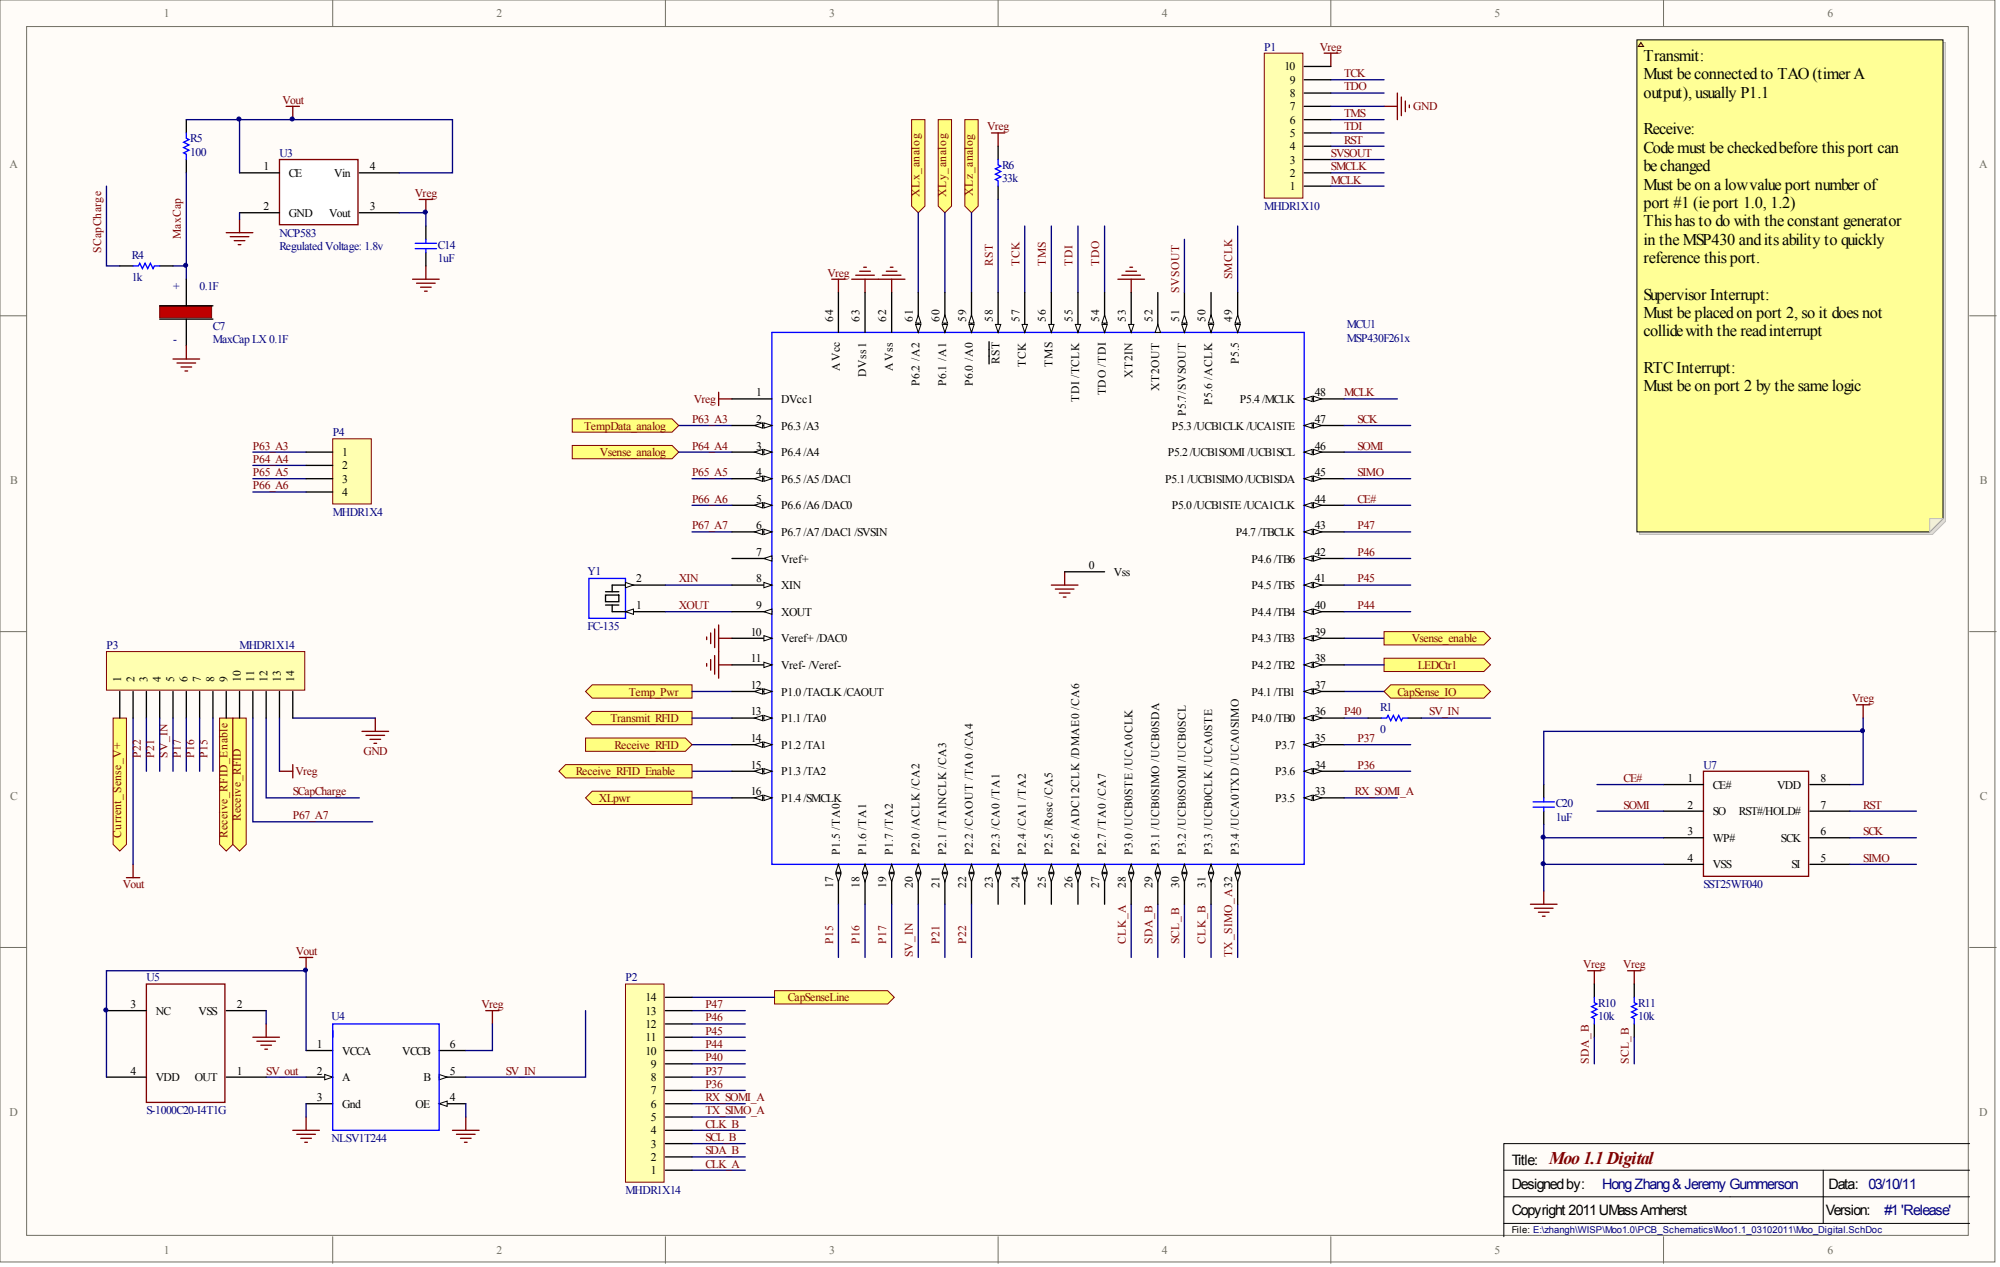
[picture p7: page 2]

Transmit:
Must be connected to TAO (timer A
output), usually P1.1

Receive:
Code must be checked before this port can
be changed
Must be on a lowvalue port number of
port #1 (ie port 1.0, 1.2)
This hasto do with the constant generator
in the MSP430 and its ability to quickly
reference this port.

Supervisor Interrupt:
Must be placed on port 2, so it does not
collide with the read interrupt

RTCInterrupt:
Must be on port 2 by the same logic

Designed by: Hong Zhang & Jeremy Gummerson | Data: 03/10/11

Copyright 2011 UMass Amherst

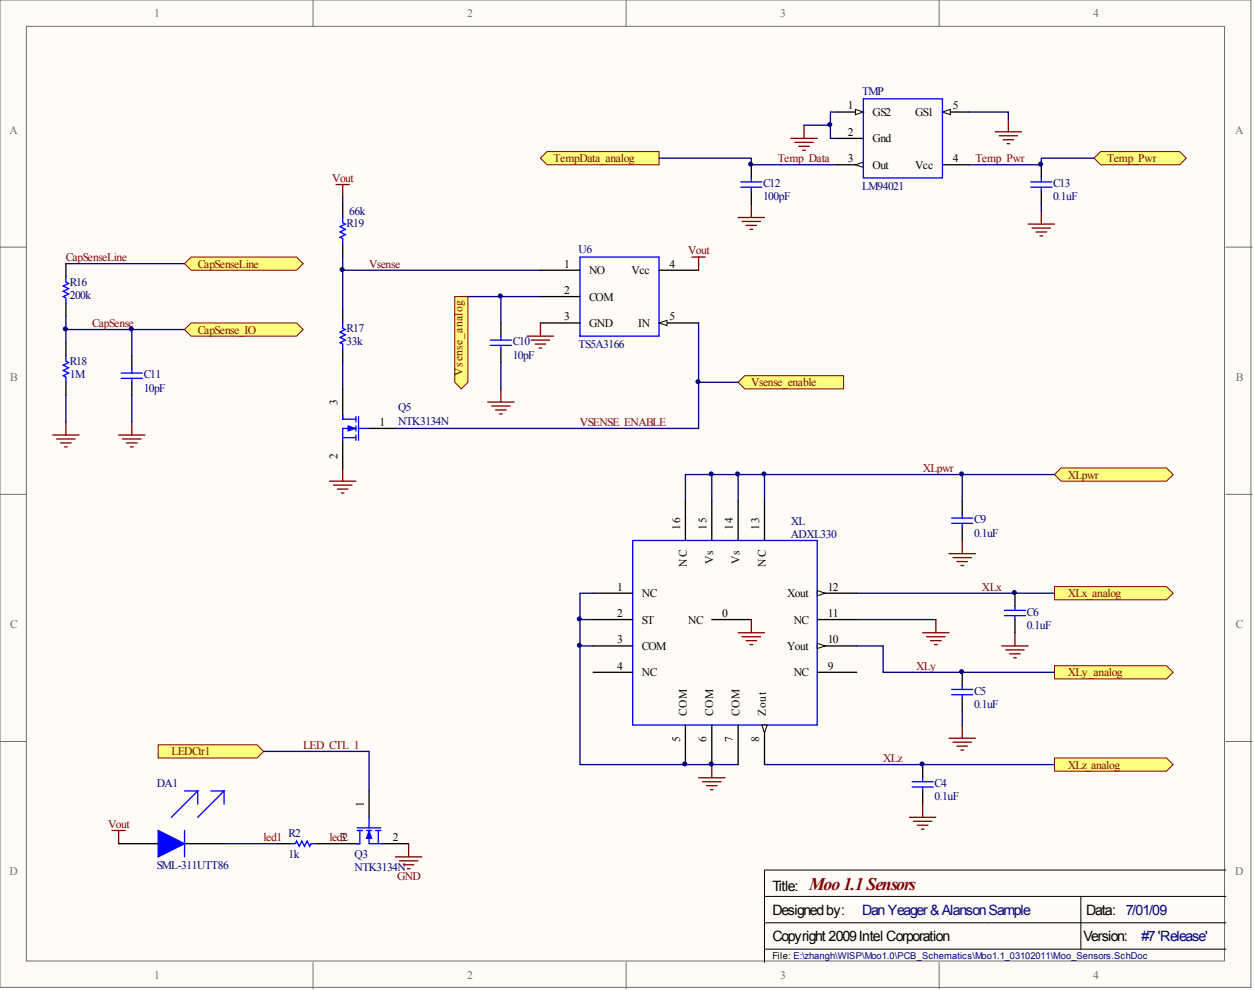
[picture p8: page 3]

Designed by: Dan Yeager & Alanson Sample | Data: 7/01/09

Copyright 2009 Intel Corporation | Version: #7 'Release'

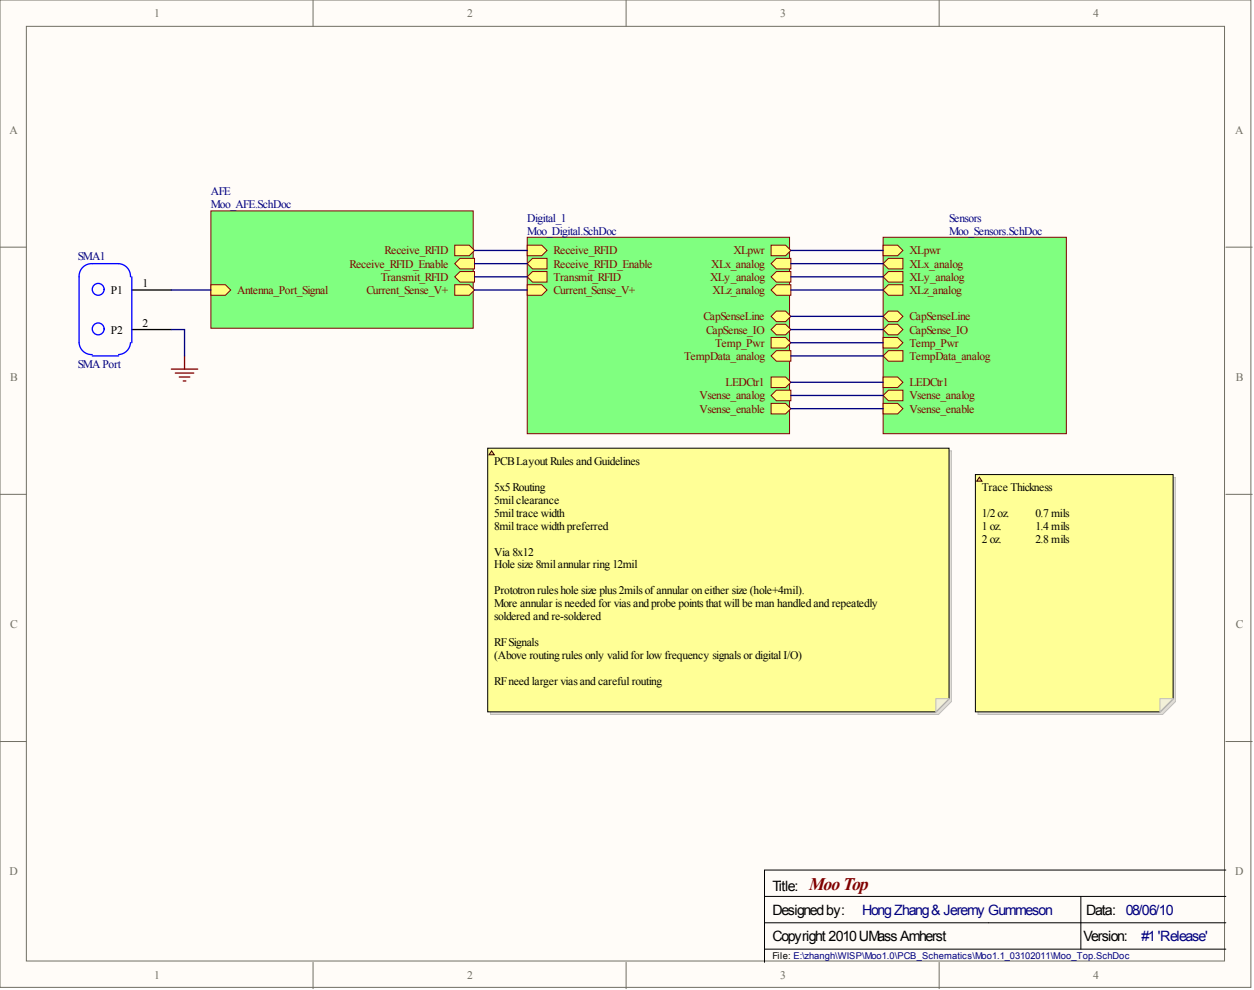
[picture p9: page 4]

Via 8x12
Hole size 8mil annular ring 12mil

Prototron rules hole size plus 2mils of annular on either size (hole+4mil).
More annular is needed for vias and probe pointsthat will be man handled and repeatedly
soldered and re-soldered

RFSignals
(Above routing rules only valid for low frequency signals or digital I/O)

RFneed larger vias and careful routing

Designed by: Hong Zhang & Jeremy Gummeson | Data: 08/06/10

Copyright 2010 UMass Amherst

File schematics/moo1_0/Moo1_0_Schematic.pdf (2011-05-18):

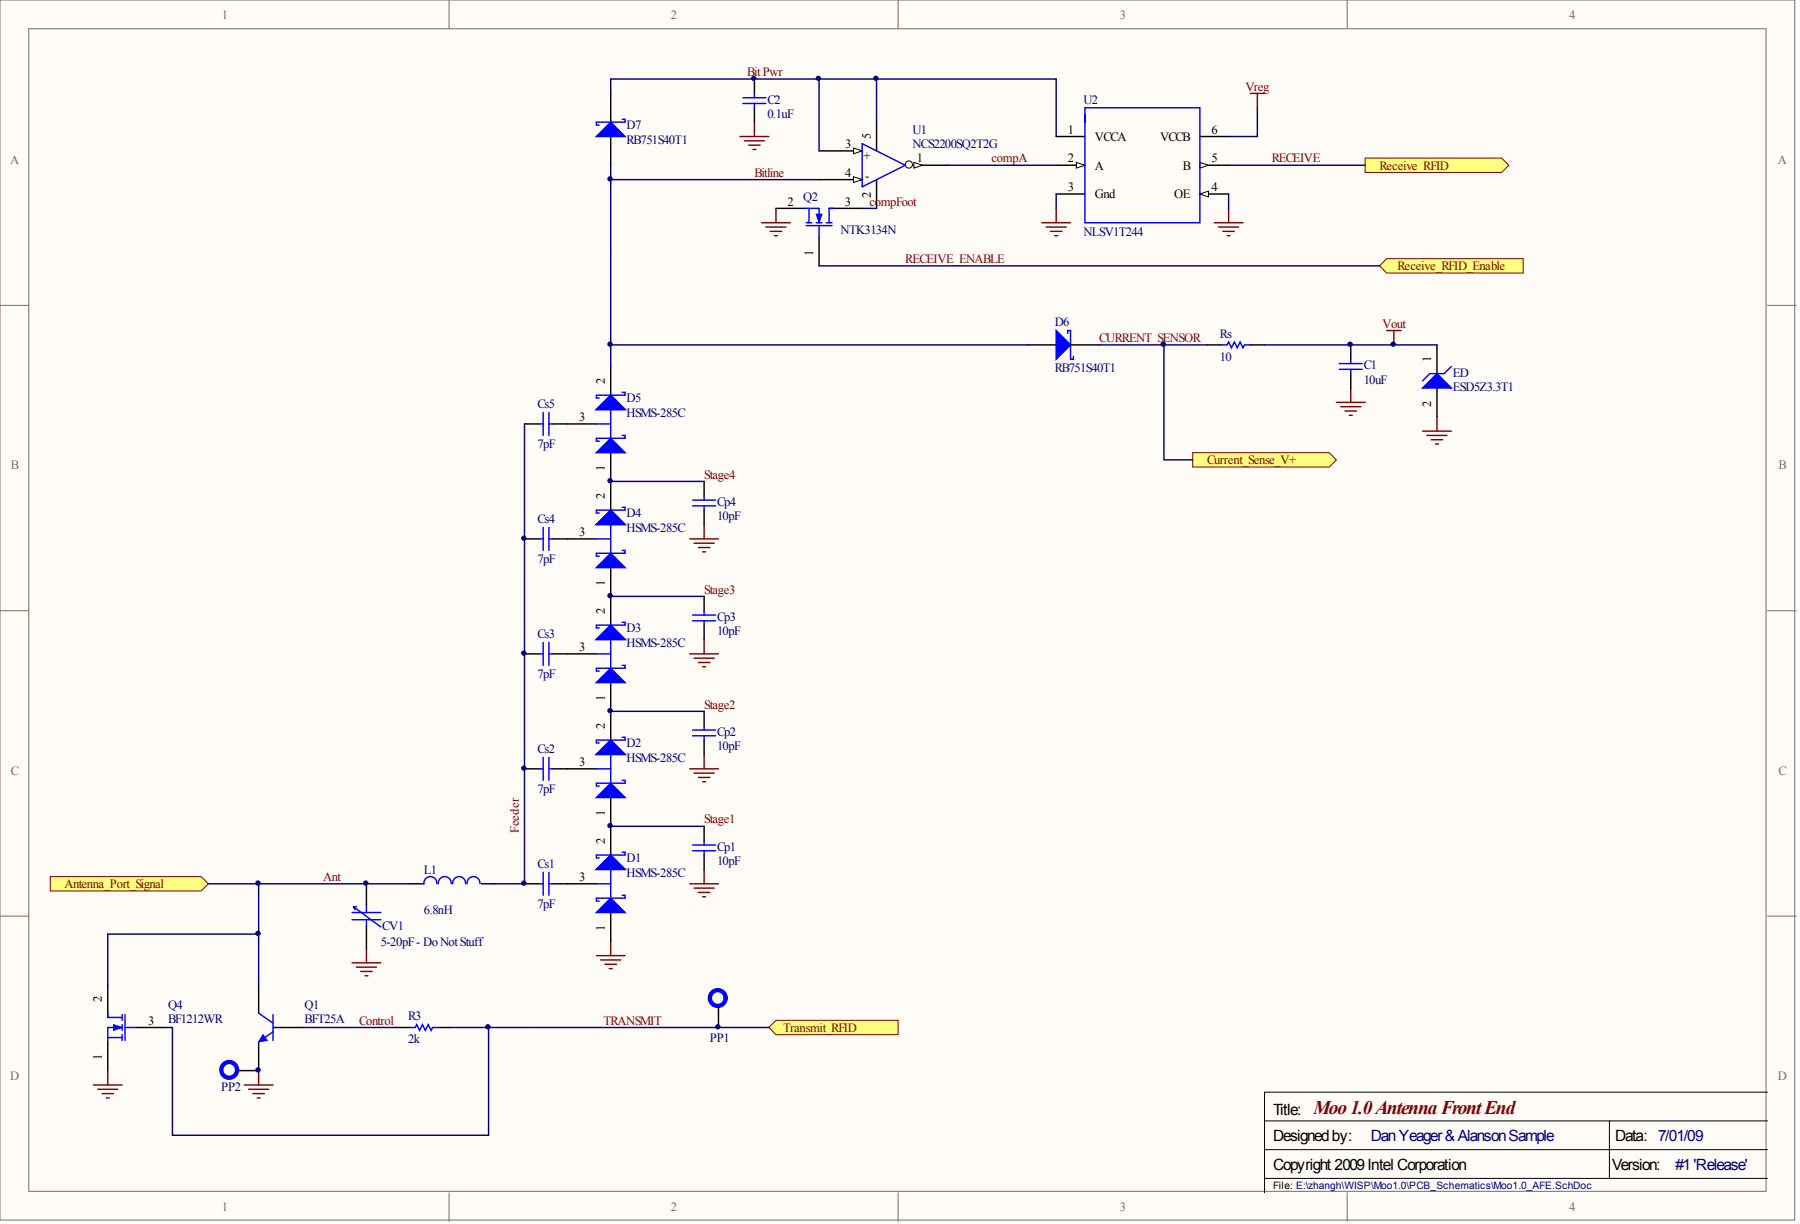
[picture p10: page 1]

Designed by: Dan Yeager & Alanson Sample | Data: 7/01/09

Copyright 2009 Intel Corporation | Version: #1 'Release'

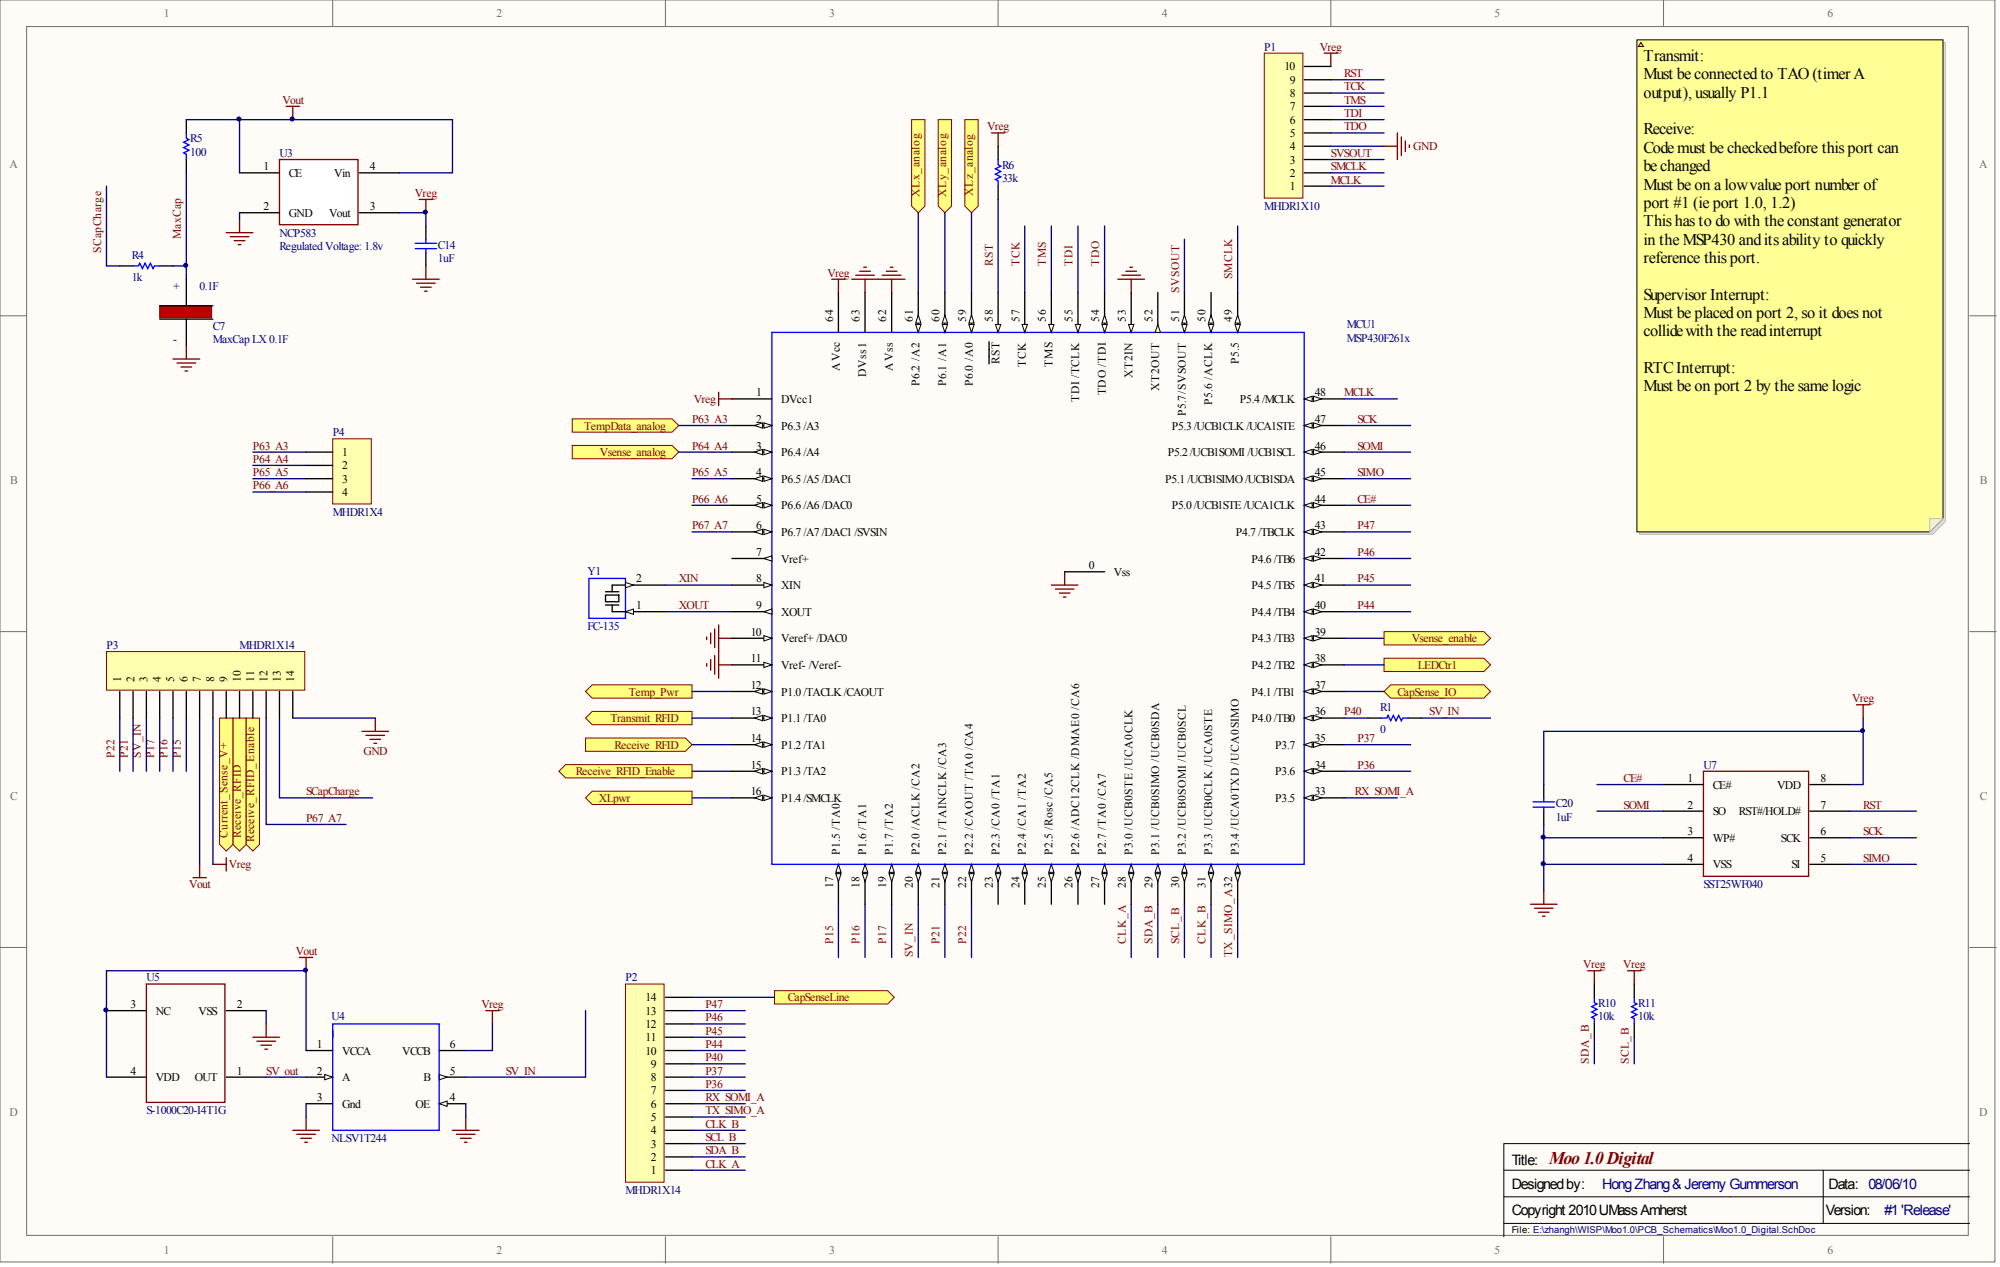
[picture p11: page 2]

Transmit:
Must be connected to TAO (timer A
output), usually P1.1

Receive:
Code must be checked before this port can
be changed
Must be on a lowvalue port number of
port #1 (ie port 1.0, 1.2)
This hasto do with the constant generator
in the MSP430 and its ability to quickly
reference this port.

Supervisor Interrupt:
Must be placed on port 2, so it does not
collide with the read interrupt

RTCInterrupt:
Must be on port 2 by the same logic

Designed by: Hong Zhang & Jeremy Gummerson | Data: 08/06/10

Copyright 2010 UMass Amherst

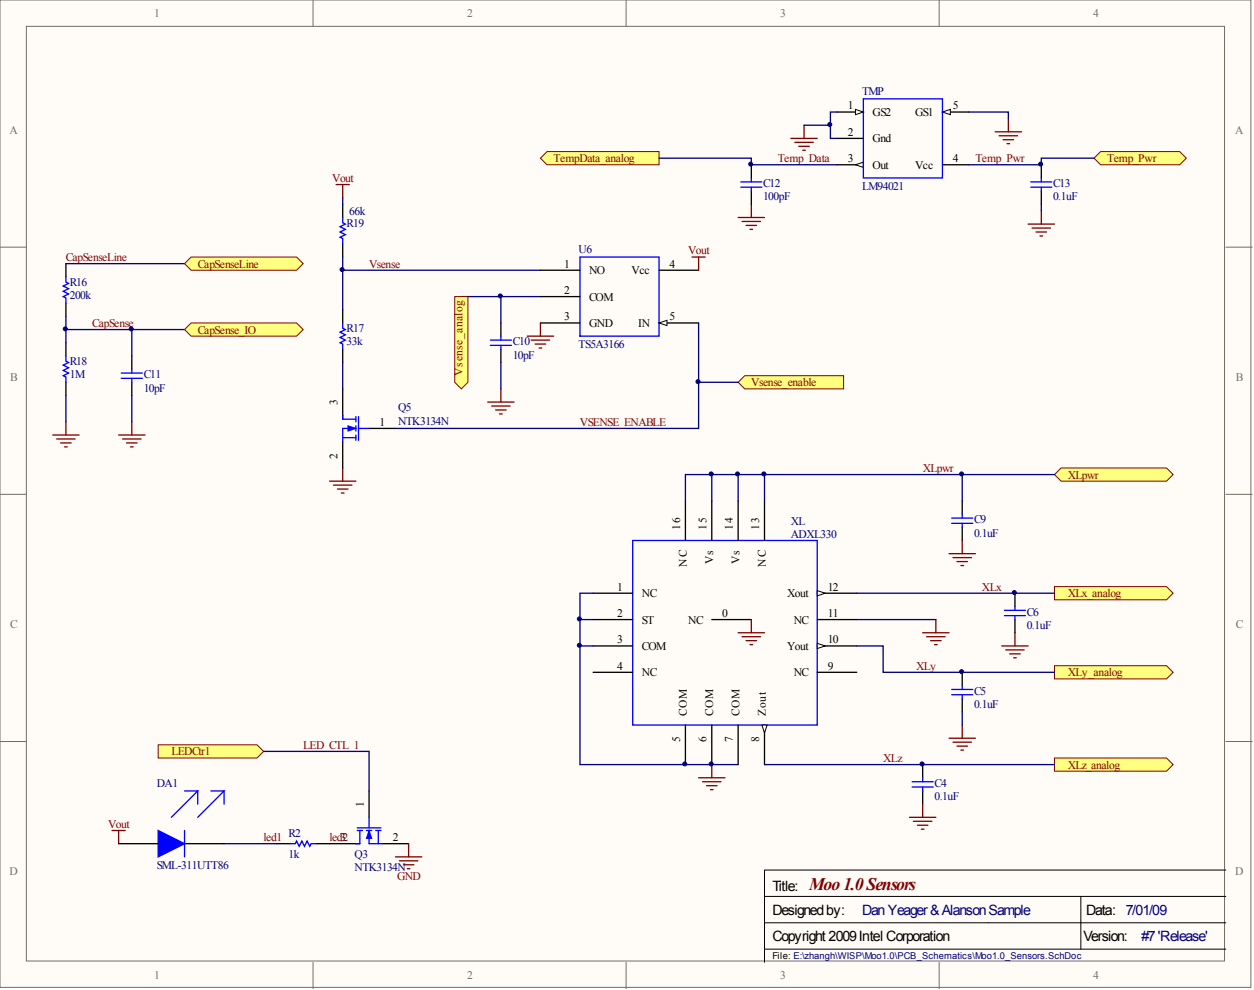
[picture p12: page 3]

Designed by: Dan Yeager & Alanson Sample | Data: 7/01/09

Copyright 2009 Intel Corporation | Version: #7 'Release'


Via 8x12
Hole size 8mil annular ring 12mil

Prototron rules hole size plus 2mils of annular on either size (hole+4mil).
More annular is needed for vias and probe pointsthat will be man handled and repeatedly
soldered and re-soldered

RFSignals
(Above routing rules only valid for low frequency signals or digital I/O)

RFneed larger vias and careful routing

Designed by: Hong Zhang & Jeremy Gummeson | Data: 08/06/10

Copyright 2010 UMass Amherst


Comment | Description | Designator | Footprint | LibRef | Quantity
Ceramic_Chip_Cap acitor | Ceramic Capacitor -Standard | C1 | 0805 | Ceramic_Chip_Cap acitor | 1

Ceramic_Chip_Cap acitor | Ceramic Capacitor -Standard | C2, C4, C5, C6, C9, C10, C11, C12, C13, C14, C20, Cp1, Cp2, Cp3, Cp4, Cs1, Cs2, Cs3, Cs4, Cs5 | 0402 | Ceramic_Chip_Cap acitor | 20

MaxCap LX 0.1F | MaxCap LX 0.1F, low leakage supper cap 5.5v | C7 | Maxcap LX 0.1F | MaxCap LX 0.1F | 1

Var Cap | Var-Cap 603 Compatible, DK: 490-2009 & SG2026CT | CV1 | Var-Cap_603 | Var-Cap/603 | 1

HSMS-285C | Agilent Schottky Diode, Bridge Quad, HSMS-285C | D1, D2, D3, D4, D5 | SOT-323, HSMS-285C | HSMS-285C | 5

RB751S40T1 | Schottky Diode | D6, D7 | SOD-523 | RB751S40T1, Schottky Diode | 2

SML-311UTT86 | LED 630NM RED WTR CLR 0603 SMD | DA1 | LED-0603 | SML-311UTT86 | 1

ESD5Z3.3T1 | 5V Overvoltage Protection Zener | ED | SOD-523 | ESD5Z3.3T1 | 1

Inductor | Inductor | L1 | 0603 | Inductor | 1
MSP430F261x | 64PM MSP430F261x | MCU1 | 64-PM | MSP430F261x | 1

MHDR1X10 | Header, 10-Pin | P1 | MHDR1X10 | MHDR1X10 | 1

MHDR1X14 | Header, 14-Pin | P2, P3 | MHDR1X14 | MHDR1X14 | 2

MHDR1X4 | Header, 4-Pin | P4 | MHDR1X4 | MHDR1X4 | 1
Probe Point | Probe Point for debug | PP1, PP2 | Probe Point | Probe Point | 2

BFT25A | NPN 5 GHz Wideband Transistor | Q1 | SOT-23 | BFT25A | 1

NTK3134N | Powe Mosfet 20V, 890mA, Single N-channel | Q2, Q3, Q5 | SOT723 | NTK3134N | 3

BF1212WR | | Q4 | sot343r | BF1212 | 1

Thick Film Chip Resistor | Thick Film Chip Resistor | R1, R2, R3, R4, R5, R6, R10, R11, R16, R17, R18, R19, Rs | 0402 | Thick Film Chip Resistor | 13

SMA Port | Two pin SMA connector wisp | SMA1 | SMA Port | SMA Port | 1

LM94021 | Temperature Sensor | TMP | SC70 | LM94021 | 1

NCS2200SQ2T2G | On Semi 10uA Comparator | U1 | sc70-5 | NCS2200SQ2T2G | 1

NLSV1T244 | Level Shifter: 1-Bit Dual-Supply Non-Inverting Level Translator | U2, U4 | UDFN6 | NLSV1T244 | 2

NCP583 | Ultra-Low Iq 150mA CMOS LDO Regulator with Enable | U3 | SC82-AB | NCP583 | 1

S-1000C20-I4T1G | | U5 | SNT-4A | S-1000C20-I4T | 1
TS5A3166 | TI Analog Switch 100nA 1ohm Normally Open | U6 | sc70-5 | TS5A3166 | 1

SST25WF040 | Serial Flash Memory - 8 Lead SOIC Package | U7 | SOIC8 | SST25WF040 | 1

ADXL330 | Analog Devices 3D Accelerometer | XL | 16-QFN | ADXL330k | 1



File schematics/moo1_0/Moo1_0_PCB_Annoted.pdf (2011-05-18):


Moo 1.0 Amherst C12 C14; MCU1; University Of; SPQR Lab; TMP; Massachusetts

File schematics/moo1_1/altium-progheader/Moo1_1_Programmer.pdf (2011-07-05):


RST TMS TCK TDI TDO



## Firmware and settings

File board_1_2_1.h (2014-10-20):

/* See license.txt for license information. */

#ifndef BOARD_H
#define BOARD_H

#include <msp430x26x.h>

// Hardware definitions for Moo 1.0 and 1.1 (MSP430F2618)
// (derived from Intel WISP 4.1 DL ["Blue WISP"] definitions)
// See the schematics/ directory for pinouts and diagrams.

#define USE_2618  1

// Define what each bit of each port is used for

// Port 1
#define  TEMP_POWER           BIT0  //  output
#define  TX_PIN               BIT1  //  output
#define  RX_PIN               BIT2  //  input
#define  RX_EN_PIN            BIT3  //  output
#define  DIGITAL_ACCEL_POWER  BIT4  //  output
#define  DEBUG_1_5            BIT5  //  output/input
#define  DEBUG_1_6            BIT6  //  output/input
#define  DEBUG_1_7            BIT7  //  output/input

// Port 2
//Supervisor in: PCB is designed to P6.7, should wire connect P6.7 and P2.0
#define  VOLTAGE_SV_PIN       BIT0  //  output/input
#define  DIGITAL_ACCEL_INT1   BIT1  //  output/input
#define  DIGITAL_ACCEL_INT2   BIT2  //  output/input
#define  IDLE_2_3             BIT3  //  idle          pin
#define  IDLE_2_4             BIT4  //  idle          pin
#define  IDLE_2_5             BIT5  //  idle          pin
#define  IDLE_2_6             BIT6  //  idle          pin
#define  IDLE_2_7             BIT7  //  idle          pin

// Port 3
#define  DIGITAL_ACCEL_CLK   BIT0  //  output
#define  SDA_B               BIT1  //  input (connected to 10k pullup res)
#define  SCL_B               BIT2  //  input (connected  to          10k     pullup  res)
#define  CLK_B               BIT3  //  output unless externally driven
#define  DIGITAL_ACCEL_MOSI  BIT4  //  output
#define  DIGITAL_ACCEL_MISO  BIT5  //  input
#define  DIGITAL_ACCEL_SEL   BIT6  //  output
#define  DEBUG_3_7           BIT7  //  output/input

// Port 4
#define DEBUG_4_0      BIT0       // connect to SV_IN by 0 ohm
#define CAP_SENSE      BIT1       // output/input
#define LED_POWER      BIT2       // output
#define VSENSE_POWER   BIT3       // output
#define DEBUG_4_4      BIT4       // output/input
#define DEBUG_4_5      BIT5       // output/input
#define DEBUG_4_6      BIT6       // output/input
#define DEBUG_4_7      BIT7       // output/input

// Port 5
#define FLASH_CE       BIT0       // output
#define FLASH_SIMO     BIT1       // output
#define FLASH_SOMI     BIT2       // input
#define FLASH_SCK      BIT3       // output
#define DEBUG_5_4      BIT4       // output unless externally driven
#define DEBUG_5_5      BIT5       // output unless externally driven
#define IDLE_5_6       BIT6       // idle pin
#define DEBUG_5_7      BIT7       // output unless externally driven

// Port 6
#define  DEBUG_6_0           BIT0  //  input
#define  DEBUG_6_1           BIT1  //  input
#define  IDLE_6_2            BIT2  //  input
#define  TEMP_EXT_IN         BIT3  //  input
#define  VSENSE_IN           BIT4  //  input
#define  DEBUG_6_5           BIT5  //  output unless externally driven
#define  DEBUG_6_6           BIT6  //  output unless externally driven
#define  DEBUG_6_7           BIT7  //  input

// Port 8: Zhangh, need to reconfirm
#define CRYSTAL_IN     BIT7       // input
#define CRYSTAL_OUT    BIT6       // output

// Analog Inputs (ADC In Channel)
#define INCH_DEBUG_6_0   INCH_0
#define INCH_DEBUG_6_1   INCH_1
#define INCH_DEBUG_6_2   INCH_2
#define INCH_TEMP_EXT_IN INCH_3
#define INCH_VSENSE_IN   INCH_4
#define INCH_DEBUG_6_5   INCH_5
#define INCH_DEBUG_6_6   INCH_6

#define DRIVE_ALL_PINS  \
  P1OUT = 0;  \
  P2OUT = 0;  \
  P3OUT = 0;  \
  P4OUT = 0;  \
  P5OUT = 0;  \
  P6OUT = 0;  \
  P8OUT = 0;  \
  P1DIR = TEMP_POWER | DIGITAL_ACCEL_POWER | TX_PIN | RX_EN_PIN; \
  P4DIR = CAP_SENSE | LED_POWER | VSENSE_POWER; \
  P5DIR = FLASH_CE | FLASH_SIMO | FLASH_SCK; \
  P8DIR = CRYSTAL_OUT;

 /* Between 1.6MHz and 3.0 MHz (from datasheet) */
#define SEND_CLOCK  \
  BCSCTL1 = XT2OFF + RSEL3 + RSEL0 ; \
    DCOCTL = DCO2 + DCO1 ;
/* Between 2.60MHz and 4.75MHz (from datasheet + datasheet equations) */
#define RECEIVE_CLOCK \
  BCSCTL1 = XT2OFF + RSEL3 + RSEL1 + RSEL0; \
  DCOCTL = 0; \
  BCSCTL2 = 0; // Rext = ON
  
  
#define DEBUG_PINS_ENABLED            0
#if DEBUG_PINS_ENABLED
#define DEBUG_PIN5_HIGH               P3OUT |= BIT5;
#define DEBUG_PIN5_LOW                P3OUT &= ~BIT5;
#else
#define DEBUG_PIN5_HIGH
#define DEBUG_PIN5_LOW
#endif

#endif

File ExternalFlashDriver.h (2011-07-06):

/*Software Driver

SST25WF040 4 Mbit Serial Flash Memory

October 11, 2010, Rev. 1.0

ABOUT THE SOFTWARE
This application note provides software driver examples for SST25WF040,
Serial Flash. Extensive comments are included in each routine to describe
the function of each routine.  The interface coding uses polling method
rather than the SPI protocol to interface with these serial devices.  The
functions are differentiated below in terms of the communication protocols
(uses Mode 0) and specific device operation instructions. This code has been
designed to compile using the Keil compiler.


ABOUT THE SST25WF040

Companion product datasheets for the SST25WF040 should be reviewed in
conjunction with this application note for a complete understanding
of the device.


Device Communication Protocol(pinout related) functions:

Functions                    		Function
------------------------------------------------------------------
init					Initializes clock to set up mode 0.
Send_Byte				Sends one byte using SI pin to send and
					shift out 1-bit per clock rising edge
Get_Byte				Receives one byte using SO pin to receive and shift
					in 1-bit per clock falling edge
Poll_SO					Used in the polling for RY/BY# of SO during AAI
                        programming
CE_High					Sets Chip Enable pin of the serial flash to high
CE_Low					Clears Chip Enable of the serial flash to low
Reset_Hold_Low			Clears Hold/Reset pin to make serial flash hold	or reset
UnReset_Hold			Dereset/Unholds the serial flash
WP_Low					Clears WP pin to make serial flash write protected
UnWP					Disables write protection pin

Note:  The pin names of the SST25WF040 are used in this application note. The
associated test code will not compile unless these pinouts (SCK, SI, SO, SO, CE,
WP, Reset_Hold) are pre-defined on your software which should reflect your
hardware interfaced.


Device Operation Instruction functions:

Functions                    		Function
------------------------------------------------------------------
Read_Status_Register			Reads the status register of the serial flash
EWSR					Enables the Write Status Register
WRSR					Performs a write to the Status Register
WREN					Write enables the serial flash
WRDI					Write disables the serial flash
EBSY					Enable SO to output RY/BY# status during AAI programming
DBSY					Disable SO to output RY/BY# status during AAI
                        programming
Read_ID					Reads the manufacturer ID and device ID
Jedec_ID_Read				Reads the Jedec ID
Read					Reads one byte from the serial flash and returns byte
                        (max of 20 MHz CLK frequency)
Read_Cont				Reads multiple bytes(max of 20 MHz CLK frequency)
HighSpeed_Read			Reads one byte from the serial flash and returns byte
                        (max of 40 MHz CLK frequency)
HighSpeed_Read_Cont			Reads multiple bytes(max of 40 MHz CLK frequency)
Byte_Program				Program one byte to the serial flash
Auto_Add_IncA				Initial Auto Address Increment process
Auto_Add_IncB				Successive Auto_Address_Increment process after AAI
                            initiation
Auto_Add_IncA_EBSY			Initial Auto Address Increment process with EBSY
Auto_Add_IncB_EBSY			Successive Auto_Address_Increment process after AAI
                            initiation with EBSY
Chip_Erase				Erases entire serial flash
Sector_Erase				Erases one sector (4 KB) of the serial flash
Block_Erase_32K				Erases 32 KByte block memory of the serial flash
Block_Erase_64K				Erases 64 KByte block memory of the serial flash
Wait_Busy				Polls status register until busy bit is low
EHLD					Enables Hold# pin functionality of the RST#/HOLD# pin
*/


//"C" LANGUAGE DRIVERS

/********************************************************************/
/* Copyright Microchip Technology Inc.  1994-2010	                */
/* Example "C" language Driver of SST25WF040 Serial Flash	        */
/* Hardik Patel, Microchip Technology Inc.                          */
/*                                                                  */
/* Revision 1.0, October 11, 2010			  	                    */
/*                                                                  */
/*								                                    */
/********************************************************************/
#include "msp430x26x.h"
#define CE    0x01
#define SIMO  0x02
#define SOMI  0x04
#define SCK   0x08

/* Function Prototypes */

void init();
void Send_Byte(unsigned char out);
unsigned char Get_Byte();
void Poll_SO();
void CE_High();
void CE_Low();
void Reset_Hold_Low();
void UnReset_Hold();
void WP_Low();
void UnWP();
unsigned char Read_Status_Register();
void EWSR();
void WRSR(unsigned char byte);
void WREN();
void WRDI();
void EBSY();
void DBSY();
void EHLD();
unsigned char Read_ID(unsigned char ID_addr);
unsigned long Jedec_ID_Read();
unsigned char Read(unsigned long Dst);
void Read_Cont(unsigned long Dst, unsigned long no_bytes);
unsigned char HighSpeed_Read(unsigned long Dst);
void HighSpeed_Read_Cont(unsigned long Dst, unsigned long no_bytes);
void Byte_Program(unsigned long Dst, unsigned char byte);
void Auto_Add_IncA(unsigned long Dst, unsigned char byte1, unsigned char byte2);
void Auto_Add_IncB(unsigned char byte1, unsigned char byte2);
void Auto_Add_IncA_EBSY(unsigned long Dst, unsigned char byte1,
        unsigned char byte2);
void Auto_Add_IncB_EBSY(unsigned char byte1, unsigned char byte2);
void Chip_Erase();
void Sector_Erase(unsigned long Dst);
void Block_Erase_32K(unsigned long Dst);
void Block_Erase_64K(unsigned long Dst);
void Wait_Busy();
void Wait_Busy_AAI();



unsigned char upper_128[128];	/* global array to store read data */
					

/************************************************************************/
/* PROCEDURE: init							*/
/*									*/
/* This procedure initializes the SCK to low. Must be called prior to 	*/
/* setting up mode 0.							*/
/*									*/
/* Input:								*/
/*		None							*/
/*									*/
/* Output:								*/
/*		SCK							*/
/************************************************************************/
void init()
{
	P5OUT &= ~SCK;	/* set clock to low initial state */
}

/************************************************************************/
/* PROCEDURE: Send_Byte							*/
/*									*/
/* This procedure outputs a byte shifting out 1-bit per clock rising	*/
/* edge on the the SI pin(LSB 1st).					*/
/*									*/
/* Input:								*/
/*		out							*/
/*									*/
/* Output:								*/
/*		SI							*/
/************************************************************************/
void Send_Byte(unsigned char out)
{
	
	unsigned char i = 0;
	for (i = 0; i < 8; i++)
	{
		
		if ((out & 0x80) == 0x80)	/* check if MSB is high */
			P5OUT |= SIMO;
		else
			P5OUT &= ~SIMO;		/* if not, set to low */
		P5OUT |= SCK;			/* toggle clock high */
		out = (out << 1);		/* shift 1 place for next bit */
		P5OUT &= ~SCK;			/* toggle clock low */
	}
}
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

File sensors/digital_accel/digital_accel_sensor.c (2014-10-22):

#include "digital_accel_sensor.h"
#include "inttypes.h"
#include "board.h"
#include "compiler.h"

#define _ACCEL_SPI_BUF_SIZE 64
static struct {
	uint8_t op;
	uint8_t address;
	uint8_t *buf;
	uint16_t bufsize;
	uint16_t pos;
	enum {
		EDigitalAccelStateWaiting,
		EDigitalAccelStateCommand,
		EDigitalAccelStateAddress,
		EDigitalAccelStateReadFirst,
		EDigitalAccelStateData,
		EDigitalAccelStateComplete,
	} state;
} _accel_spi_state;


/* Private helper functions for this file, all declared static */
static void _digital_accel_blocking_tx(uint8_t data);
static void _digital_accel_blocking_rx();
static void _digital_accel_spi_select();
static void _digital_accel_spi_deselect();
/* End private helper functions */

void digital_accel_spi_start(uint8_t op, uint8_t address, uint8_t * data, uint16_t len) {
	IE2 &= ~(UCA0TXIE | UCA0RXIE);
	_accel_spi_state.op = op;
	_accel_spi_state.address = address;
	_accel_spi_state.buf = data;
	_accel_spi_state.bufsize = len;
	_accel_spi_state.pos = 0;
	_accel_spi_state.state = EDigitalAccelStateCommand;
	IE2 |= UCA0TXIE;
}

uint8_t digital_accel_spi_in_use() {
	return _accel_spi_state.state != EDigitalAccelStateWaiting;
}

uint8_t digital_accel_has_data() {
	uint8_t data = 0;
#if MOO_VERSION == MOO1_2
	data = P6IN & DIGITAL_ACCEL_INT1;
#else
	data = P2IN & DIGITAL_ACCEL_INT1;
#endif
	return data;
}

uint8_t digital_accel_spi_complete() {
	return _accel_spi_state.state == EDigitalAccelStateComplete;
}

void digital_accel_spi_buf_mark_read() {
	if (_accel_spi_state.state == EDigitalAccelStateComplete) {
		_accel_spi_state.state = EDigitalAccelStateWaiting;
	}
}

void _digital_accel_continue_spi(void) {
	switch (_accel_spi_state.state) {
	case EDigitalAccelStateWaiting:
		/* Do nothing */
		break;
	case EDigitalAccelStateCommand:
		P3OUT &= ~(DIGITAL_ACCEL_SEL); /* Select SPI slave, active low */
		UCA0TXBUF = _accel_spi_state.op;
		_accel_spi_state.state = EDigitalAccelStateAddress;
		break;
	case EDigitalAccelStateAddress:
		UCA0TXBUF = _accel_spi_state.address;
		if (_accel_spi_state.op == DIGITAL_ACCEL_WRITE) {
			_accel_spi_state.state = EDigitalAccelStateData;
		}
		else {
			_accel_spi_state.state = EDigitalAccelStateReadFirst;
		}
		break;
	case EDigitalAccelStateReadFirst:
		IFG2 &= ~(UCA0RXIFG); // Clear read interrupt so we can wait for it to be set
		IE2 &= ~UCA0TXIE;
		IE2 |= UCA0RXIE; /* If we are reading data, we want to enable the recevied interrupt */
		UCA0TXBUF = DIGITAL_ACCEL_DUMMY;
		_accel_spi_state.state = EDigitalAccelStateData;
		break;
	case EDigitalAccelStateData:
		if (_accel_spi_state.pos == _accel_spi_state.bufsize) {
			_digital_accel_spi_deselect();
			_accel_spi_state.state = EDigitalAccelStateComplete;
			IE2 &= ~UCA0RXIE;
			IE2 &= ~UCA0TXIE;
		}
		else {
			if (_accel_spi_state.op == DIGITAL_ACCEL_WRITE) {
				UCA0TXBUF = _accel_spi_state.buf[_accel_spi_state.pos++];
			}
			else {
				_accel_spi_state.buf[_accel_spi_state.pos++] = UCA0RXBUF;
				while (!(IFG2 & UCA0TXIFG));     // USCI_A0 TX buffer ready?
				UCA0TXBUF = DIGITAL_ACCEL_DUMMY;
			}
		}
	case EDigitalAccelStateComplete:
		/* @TODO Assert, this should never happen */
		break;

	}
}

ISR(USCIAB0RX_VECTOR,_digital_accel_read_int) {
	_digital_accel_continue_spi();
}

ISR(USCIAB0TX_VECTOR,_digital_accel_write_int) {
	_digital_accel_continue_spi();
}

/*
 * Selects pin modes for pins of the accelerometer, in case they were configured
 * as GPIO pins.
 *
 * This function by itself will not setup the SPI interface.
 */
void digital_accel_setup_pins() {
	/* Accelerometer power Setup */
	P1SEL &= ~(DIGITAL_ACCEL_POWER); // Set P1.4 to GPIO
	P1DIR |= DIGITAL_ACCEL_POWER;    // Set Pin direction to output
	/* End Accelerometer Power Setup */

	/* Configure UCA0* Pins */
	P3SEL |= DIGITAL_ACCEL_CLK + DIGITAL_ACCEL_MOSI + DIGITAL_ACCEL_MISO;
	P3SEL &= ~(DIGITAL_ACCEL_SEL); // Non-standard select pin by design
	P3DIR |= DIGITAL_ACCEL_SEL;    // Again, setting up non-standard sel pin
	/* End configure UCA0* Pins */
	
#if MOO_VERSION == MOO1_2
	P6SEL &= ~DIGITAL_ACCEL_INT1;
	P6DIR &= ~DIGITAL_ACCEL_INT1;
#else
	P2SEL &= ~DIGITAL_ACCEL_INT1;
	P2DIR &= ~DIGITAL_ACCEL_INT1;
#endif
}

/*
 * Turns on the accelerometer.
 *
 * Expects pin 1.4 to be setup properly already (GPIO mode selected, direction
 * set to out). If it is not properly configured, then call
 * digital_accel_setup_pins() first.
 */
void digital_accel_power_on() {
	P1OUT |= DIGITAL_ACCEL_POWER;
}

void digital_accel_power_off() {
	P1OUT &= ~(DIGITAL_ACCEL_POWER);
}

void digital_accel_init() {
	/*
	 * Setup for:
	 *   - Synchronous Mode
	 *   - 3-pin SPI Mode (Using non-standard select pin)
	 *   - Master Mode
	 *   - 8-bit character length
	 *   - MSB first
	 *   - CPOL = 0/CKPL = 0
	 *   - CPHA = 0/CKPH = 1
	 * See http://www.ti.com/lit/ug/slau144j/slau144j.pdf page 445 for details
	 */
	UCA0CTL0 = UCCKPH + UCMSB + UCMST + UCSYNC;
	/*
	 * Setup for:
	 *   - Clock: SMCLK
	 *   - Reset: Leave in last reset state
	 */
	UCA0CTL1 |= UCSSEL_2;

	/*
	 * Clock divider = /1
	 * Clock must be between 1MHz and 5MHz, per the ADXL362 spec
	 */
	UCA0BR0 = 0x01;                           // /1
	UCA0BR1 = 0;                              //

	/*
	 * Take SPI driver on MSP430 out of reset
	 */
	UCA0CTL1 &= ~(UCSWRST);
}

void digital_accel_set_interrupt(enum EDigitalAccelInt interrupt, uint8_t source) {
	if (interrupt == EDigitalAccelInt_Int1) {
		digital_accel_write_address(DIGITAL_ACCEL_REG_INTMAP1, source);
	}
	else {
		digital_accel_write_address(DIGITAL_ACCEL_REG_INTMAP2, source);
	}
}

void digital_accel_set_power(enum EDigitalAccelMode mode, enum EDigitalAccelLowNoise noise, uint8_t flags) {
	uint8_t data;
	data = (uint8_t) mode + (uint8_t) (noise << 4) + flags;
	digital_accel_write_address(DIGITAL_ACCEL_REG_POWER_CTL, data);
}

void digital_accel_set_filter(enum EDigitalAccelRange range, enum EDigitalAccelOdr odr, uint8_t flags) {
	uint8_t data;
	data = (uint8_t) (range << 6) + (uint8_t) odr + flags;
	digital_accel_write_address(DIGITAL_ACCEL_REG_FILTER_CTL, data);
}

void digital_accel_write_address(uint8_t address, uint8_t byte) {
	digital_accel_write_burst(address, &byte, 1);
}

uint8_t digital_accel_read_address(uint8_t address) {
	uint8_t buf[1];
	digital_accel_read_burst(address, buf, 1);
	return buf[0];
}

void digital_accel_read_burst(uint8_t start_address, uint8_t * data, uint8_t len) {
	uint8_t i;
	_digital_accel_spi_select();
	_digital_accel_blocking_tx(DIGITAL_ACCEL_READ);
	_digital_accel_blocking_tx(start_address);
	for(i = 0; i < len; i++) {
		_digital_accel_blocking_rx();
		data[i] = UCA0RXBUF;
	}
	_digital_accel_spi_deselect();
}

void digital_accel_write_burst(uint8_t start_address, uint8_t * data, uint8_t len) {
	uint8_t i;
	_digital_accel_spi_select();
	_digital_accel_blocking_tx(DIGITAL_ACCEL_WRITE);
	_digital_accel_blocking_tx(start_address);
	for(i = 0; i < len; i++) {
		_digital_accel_blocking_tx(data[i]);
	}
	_digital_accel_spi_deselect();
}
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

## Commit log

2011-02-24 First commit of Moo Sample Programs
2011-03-21 attempted to add correct attributions for Moo*.c
    These files were apparently derived from TI sample code. Hong, please
    confirm that these attributions are correct.
2011-05-18 added Moo 1.0 schematic and layout diagram
2011-05-19 added moo 1.1 schematics; organized older versions
2011-06-14 corrected pindefs header (& renamed)
    [pins.h]
2011-06-16 Add Impinj RFID Reader Driver
2011-07-05 added altium designer files for moo 1.1
    [BOM_MOO11.xls, Moo1.1.PcbDoc, Moo1.1.PrjPcb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]
2011-07-05 added altium designer files for moo 1.1 programming header
    [Programmer.PcbDoc, Programmer.PrjPcb, Programmer.SchDoc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]
2011-07-06 shorten >80-char lines and trailing spaces
    [ExternalFlashDriver.h, mymoo.h, quick_accel_sensor.h]
2011-07-07 moved function prototypes from moo.c to moo.h
2011-07-08 changed BUFFER_SIZE (16) to CMD_BUFFER_SIZE (32).
    Shane Clark noted that BUFFER_SIZE=16 broke READ command parsing in
    SIMPLE_READ_COMMAND and SENSOR_DATA_IN_READ_COMMAND modes; setting it to
    32 instead made the problem go away. Future work: figure out a proper
    upper bound for READ command length in bytes and set CMD_BUFFER_SIZE to
    that instead of 32.
2011-07-12 imported flash driver from simplerpc branch
2013-08-14 internal temperature sensor
2013-09-20 Adding port1_isr.asm to allow removal or inline assembly
2013-09-20 Removing port 1.2 interrupt from moo.c
2013-09-20 Removing assembly code from moo.c and putting into send_to_reader.asm
2013-09-20 Adding timerA1_isr.asm
2013-09-20 Splitting include file out of mymoo.h, so that it can be included in an assembly file
2013-09-20 umassmoo.ewp updated to the lastest version, and including assembly files
2013-09-23 Reorganizing header files for ease of use
    In order to allow for easier inclusion in assembly files (the assembler
    cannot deal with function definitions), and to better seperate interfaces
    and configuration, I added board.h, sensor.h, and states.h. I also
    modified moo.h and mymoo.h, moving code into the new header files for
    organization
2013-10-17 Code Clean-up: Use parameter instead of global
    In quick_accel_sensor, instead of using the target variable that
    is passed, we are using the global ackReply variable. That is now
    fixed, making the code more modular.
    [quick_accel_sensor.c]
2013-11-04 Adding new sensor files
2013-11-12 Adding the SPI driver for the accelerometer device.
    Adding two levels of files to suppor the accelerometer. First, we
    added the digital_accel_sensor.c and .h files to provide the pin
    connections and the interface to use with the accelerometer. Then
    we added the code to allow the moo to actually interface with the
    board.
2013-11-14 Moving pin specification from digital_accel_sensor.h to board.h, because they are specific to the board
2013-11-25 Adding schematics for Moo 1.2
    Schematics include gerber files, for future board manufacturing and
    assembly, as well as PDF of schematic and bill of materials.
    [Moo1.2.GBL, Moo1.2.GBO, Moo1.2.GBP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]
2013-12-02 Digital Accel works sometimes without FET
    With these code changes, I'm able to get the moo to report back,
    with some accuracy, the accelerometer data. If the FET is attached
    at this point, we get accurate readings 100% of the time. However,
    once we detach the FET, not so much. I theorize that it's because
    the accelerometer is losing power, and we aren't giving it power
    again, but I could be wrong. According to the spec, you need to give
    5ms for the device to reach standby mode, and then 40ms for the first
    reading. That is a LONG time. I'm thinking that we just keep the
    device in powered on at all times. I probably need to power in the
    device just incase it of a power lose in the read_sensor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
    [digital_accel_sensor.c, digital_accel_sensor.h, mymoo.h]
2013-12-02 Enabling SPI interrupt based transactions
    This code allows for the SPI bus that communciates with the digital
    accelerometer to be interrupt driven. This allows for a much faster
    tag rate and (hopefully) less power usage. THERE IS CURRENTLY A BUG,
    1 times in 4 or so, we get into a state where the digital accelerometer
    never updates it's values. We just get the same data back over and over
    again. I need to look into that. It's probably something to do with
    timer a.
    [digital_accel_sensor.c, digital_accel_sensor.h]
2013-12-05 Fixing bug where board sometimes doesn't update
    Every so often, when we powered on the board, we would get into a
    state where it wouldn't update any information. The cause, we
    believe, was the 5ms that it takes to start the board. We now delay
    for 5ms using noops while we wait for the accelermeter to turn on.
    This causes some issues where, when we lose power, we now take at
    leasst 5ms to turn on. We will look at that later, but for now we
    are looking into sleeping for those 5 ms.
2013-12-10 Adding old external temp sensor to the code
2013-12-12 Adding sleep_ms function that allows the device to sleep for n milliseconds if we want too. We are using this for turning on the accelerometer, as it can take up to 5ms to turn on.
2013-12-12 Adding temp_sensor from master to this branch of code so that we can use the temperature sensor on the moo 1.2s
2013-12-13 Fixing accelerometer reference code to use the 1.5V reference, not the 2.5V reference
    [temp_sensor.c]
2014-01-09 Adding simple sensor to the moo for simple testing
    The "simple sensor" allows us to get the fastest available tag
    rate without having to worry about the sensor interface (for
    example, the SPI bus with the digital accelerometer) causing
    delays in the system that my be in some way harming the RFID
    signal analysis, or causing a timeout.
2014-02-27 Adding new code to deal with interrupts from the digital accelerometer
2014-02-27 Removing sleep_ms function
    There seems to be a problem with TimerB, in that we can "miss" it's
    interrupt and then be stuck in sleeping land forever. Therefore, I've
    removed the sleep_ms code from the moo, and have added the
    intrinsic "__delay_cycles" to busy wait instead. Because I don't plan
    on supporting this code for much longer, I think that's a fair
    solution to the problem.
    [temp_sensor.c]
2014-02-27 Switching moo version in my_moo.h
2014-02-27 Turning off power evaluation of code
2014-10-15 [sensors] Changing sensor registration
    Changed the code around so that we can easily register modules now
    instead of having an "active sensor"
2014-10-20 [Moo1.2.1] Fixing digital accel for Moo1.2
    [board_1_2_1.h, digital_accel_sensor.c, digital_accel_sensor.h]
2014-10-21 [sensor_refactor] Adding documentation, some debugging
2014-10-21 [sensor_refactor] Forgot to add files to project
2014-10-21 [sensors_refactor] Fixing linker path to not be absolute
2014-10-21 [sensors_refactor] Adding new readme
2014-10-21 [sensor_refactor] Pointing README to README.usage
2014-10-22 [moo_gnu] Initial restructure to make gcc work
    [devices.csv]
2014-10-22 [gnu] Switching to modern header file.
2014-10-22 [gnu] Error handling and compiler fixes
    [digital_accel_sensor.c]
2014-10-22 [moo_gnu] Removed extra msp430 files that we don't need
    [devices.csv]
2014-10-22 [moo_gnu] Fixing sensor api to work with GCC
    [compiler.h]
2014-11-04 [moo_gnu] Bringing timerA1_isr back into C.
    Note, these file will only work with GCC, not IAR.
2014-11-17 [bug_fix] Removing annoying Message calls
    [sensor.h]
2014-11-19 [spi_sensor] Adding spi sensor
2014-11-19 [SPI] Updating spi sensor to new registration of sensors
2014-11-19 [spi_sensor] Moving spi sensor into sensor structure
2015-04-13 [master] Fixing makefile to compile sensor objects as well
